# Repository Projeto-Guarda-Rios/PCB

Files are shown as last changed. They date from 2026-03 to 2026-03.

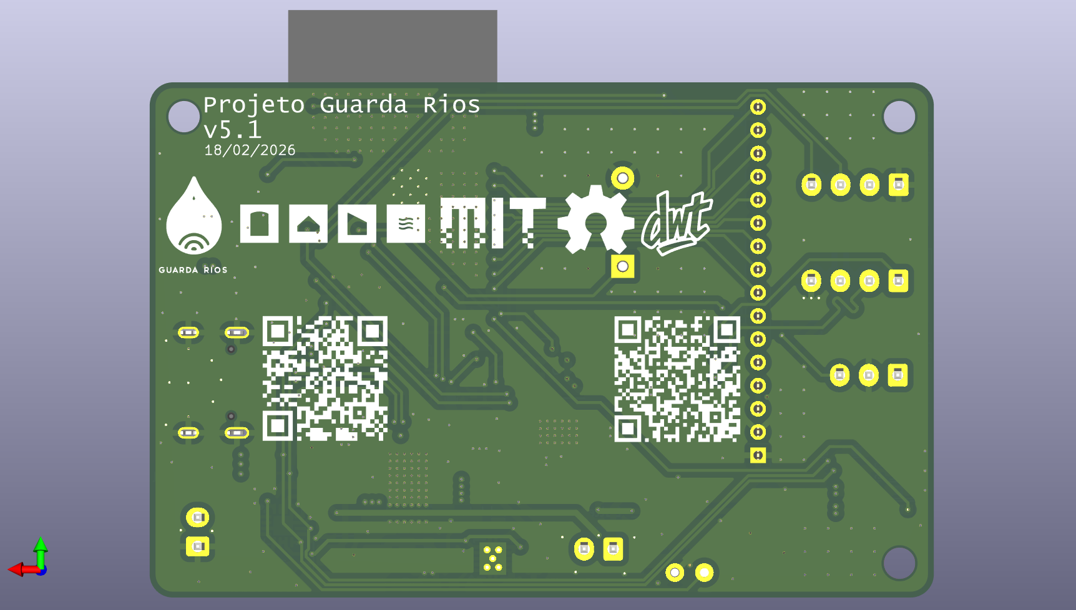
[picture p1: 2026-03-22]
PGR - PCB/Renders/PGR - 2.png

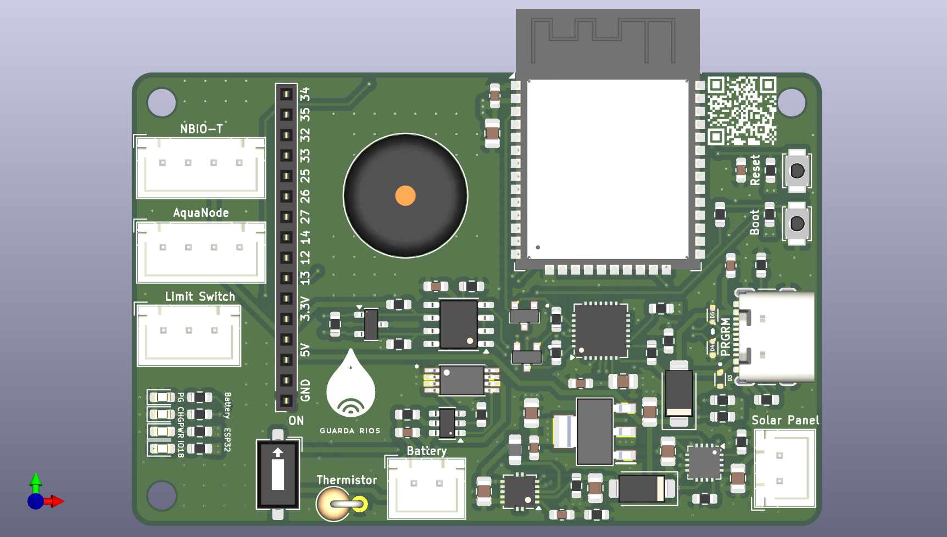
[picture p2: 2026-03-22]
PGR - PCB/Renders/PGR.png

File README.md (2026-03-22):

# Guarda-Rios PCB Repository

This repository contains all PCB design files for the **Guarda-Rios Project** — an open-source, low-cost, low-power water quality monitoring system. Multiple stations are deployed along a river so that parameter spikes between adjacent stations reveal precisely where pollution enters the waterway.

The system has two PCBs:

| Board | Role | Placement |
|---|---|---|
| **AquaNode PCB** | Submerged sensor node — reads water parameters and transmits them over RS-485 | Below waterline |
| **Main PCB (PGR)** | Station hub — receives RS-485 data, manages power (solar + 18650 Li-ion), and sends data to the cloud via NB-IoT | Above waterline |

> GitHub organisation: [github.com/Projeto-Guarda-Rios](https://github.com/Projeto-Guarda-Rios)
> Project site: [guarda-rios.pt](https://guarda-rios.pt) · Data portal: [data.guarda-rios.pt](https://data.guarda-rios.pt)

---

## Directory Structure

```
PCB/
├── AquaNode - PCB/          # AquaNode submerged sensor node
├── PGR - PCB/               # Main Station PCB
├── Datasheets/              # Component datasheets
├── Resources/               # Logos, SVGs, and images (silkscreen assets)
└── LICENSE
```

---

## AquaNode - PCB

The AquaNode is the submerged node of each station. It is built around an **STM32L053R8** microcontroller (ultra-low-power) and integrates a DS18B20 water temperature sensor (1-Wire) and a DFRobot SEN0554 turbidity sensor. Readings are encoded into the custom Guarda-Rios protocol and transmitted to the Main PCB over RS-485.

```
AquaNode - PCB/
├── Renders/                              # PNG renders of the current board
│   ├── AquaNode - PCB.png               #   Top-side render
│   └── AquaNode - PCB - 2.png           #   Bottom-side / alternate angle render
│
├── AquaNode - PCB.step                  # STEP model of the assembled board
├── AquaNode - PCB - Render.step         # STEP model used for rendering
├── AquaNode - PCB.stl                   # STL mesh of the board
│
└── AquaNode - PCB/                      # KiCAD project (current version)
    ├── AquaNode - PCB.kicad_pro         #   KiCAD project file  ← open this in KiCAD
    ├── AquaNode - PCB.kicad_pcb         #   PCB layout
    ├── AquaNode - PCB.kicad_sch         #   Schematic
    ├── footprints/                      #   Custom footprint library
    ├── symbols/                         #   Custom symbol library
    └── production/                      # Production files (PCBA) — current version
        ├── -v2.0.zip                    #   Gerbers + drill files (upload to JLCPCB)
        ├── -v2.0_bom.csv               #   Bill of Materials
        ├── -v2.0_positions.csv         #   Component placement (pick & place)
        ├── -v2.0_designators.csv       #   Designator mapping
        ├── netlist.ipc                  #   IPC netlist
        └── backups/                     #   Auto-generated production backups
```

**Key files:**
- Edit the PCB: `AquaNode - PCB/AquaNode - PCB/AquaNode - PCB.kicad_pro`
- Order the board: `AquaNode - PCB/AquaNode - PCB/production/-v2.0.zip`
- BOM for assembly: `AquaNode - PCB/AquaNode - PCB/production/-v2.0_bom.csv`
- Positions for assembly: `AquaNode - PCB/AquaNode - PCB/production/-v2.0_positions.csv`

---

## PGR - PCB

The Main PCB (PGR) is the above-water hub of each station. It is built around an **ESP32-WROOM-32D** and includes an RS-485 receiver, NB-IoT modem, BMS (battery management system), 18650 Li-ion charger, and solar charger — making each station fully self-sufficient in the field.

```
PGR - PCB/
├── Renders/                              # PNG renders of the current board
│   ├── PGR.png                          #   Top-side render
│   └── PGR - 2.png                      #   Bottom-side / alternate angle render
│
├── PGR.step                             # STEP model of the assembled board
├── PGR-Solder.step                      # STEP model showing solder joints
├── PGR.3mf                             # 3MF model (for 3D printing / Fusion 360)
│
├── PGR - PCB - v1.0-v4.0.zip           # Archived KiCAD projects (versions 1.0 – 4.0)
├── PGR - PCB - v5.0.zip                # Archived KiCAD project (version 5.0)
│
├── gerbers/                             # Gerber archives for previous board versions
│   ├── PGR-gerbers-v1.0.zip
│   ├── PGR-gerbers-v2.0.zip
│   ├── PGR-gerbers-v3.0.zip
│   ├── PGR-gerbers-v3.1.zip
│   ├── PGR-gerbers-v4.0.zip
│   ├── PGR-gerbers.zip                  #   (legacy export)
│   ├── PGR-F_Paste.zip                  #   Front paste layer export
│   └── PGR-PTH.zip                      #   PTH drill file export
│
└── PGR - PCB/                           # KiCAD project (current version)
    ├── PGR.kicad_pro                    #   KiCAD project file  ← open this in KiCAD
    ├── PGR.kicad_pcb                    #   PCB layout
    ├── PGR.kicad_sch                    #   Schematic
    ├── PGR-Library.kicad_sym           #   Custom symbol library
    ├── PGR-FootPrints.pretty/          #   Custom footprint library
    ├── footprints/                      #   Additional footprints
    ├── symbols/                         #   Additional symbols
    └── production/                      # Production files (PCBA) — current versions
        ├── PGR_PCB_v5.1.zip            #   Gerbers + drill files — latest (upload to JLCPCB)
        ├── PGR_PCB_v5.1_bom.csv        #   Bill of Materials — latest
        ├── PGR_PCB_v5.1_positions.csv  #   Component placement — latest
        ├── PGR_PCB_v5.1_designators.csv
        ├── PGR_PCB_v5.0.zip            #   Gerbers + drill files — v5.0
        ├── PGR_PCB_v5.0_bom.csv        #   Bill of Materials — v5.0
        ├── PGR_PCB_v5.0_positions.csv
        ├── PGR_PCB_v5.0_designators.csv
        ├── bom-JLCPCB Assembly Order.xls  # JLCPCB-formatted BOM for online ordering
        ├── bom.csv
        ├── designators.csv
        ├── positions.csv
        ├── netlist.ipc
        └── backups/                    # Auto-generated production backups
```

**Key files:**
- Edit the PCB: `PGR - PCB/PGR - PCB/PGR.kicad_pro`
- Order the board (latest): `PGR - PCB/PGR - PCB/production/PGR_PCB_v5.1.zip`
- BOM for assembly (latest): `PGR - PCB/PGR - PCB/production/PGR_PCB_v5.1_bom.csv`
- Positions for assembly (latest): `PGR - PCB/PGR - PCB/production/PGR_PCB_v5.1_positions.csv`
- Previous version gerbers: `PGR - PCB/gerbers/`

> Note: There are no current production files inside `PGR - PCB/gerbers/` — that directory holds archives of older board revisions only. Current production files are inside `PGR - PCB/PGR - PCB/production/`.

---

## Datasheets

Reference datasheets for ICs and components used across both PCBs.

```
Datasheets/
├── STM32L053C6.PDF                       # AquaNode MCU — STM32L053 datasheet
├── an4467-getting-started-with-stm32l0xx-hardware-development-stmicroelectronics.pdf
│                                         # STM32L0 hardware development guide (ST AppNote AN4467)
└── st485eb.pdf                           # ST485EB RS-485 transceiver (used on AquaNode)
```

---

## Resources

Images, SVGs, and logos used in PCB silkscreen layers or project documentation.

```
Resources/
├── guarda_rios_logo.svg / .png          # Official Guarda-Rios project logo
├── dwtLogo.svg                          # Designer logo
├── MIT_license_logo.svg / .png         # MIT license badge
├── open_source_logo.svg                 # Open-source hardware logo
├── open-source-hardware6230.logowik.com.webp
├── logo-colegio-ribadouro.png           # School/institution logo
│
├── AquaNodeBack.svg                     # AquaNode back silkscreen artwork
├── AquaNodeBack - Sem Logo.svg          # AquaNode back silkscreen (no logo variant)
├── BackSilkScreen.svg                   # Generic back silkscreen asset
│
├── AquaNode_v2_image_top.png            # AquaNode v2 board image — top
├── AquaNode_v2_image_bottom.png         # AquaNode v2 board image — bottom
├── PGR_v5.1_image_top.png              # PGR v5.1 board image — top
├── PGR_v5.1_image_bottom.png           # PGR v5.1 board image — bottom
│
└── Gemini_Generated_Image_iya1lhiya1lhiya1.png   # AI-generated concept image
```

---

## Hardware Summary

| Parameter | AquaNode PCB | Main PCB (PGR) |
|---|---|---|
| MCU | STM32L053R8 | ESP32-WROOM-32D |
| Sensors | DS18B20 (temp), DFRobot SEN0554 (turbidity) | — |
| Communication | RS-485 out (custom protocol) | RS-485 in · NB-IoT out |
| Power | From Main PCB via RS-485 cable | Solar + 18650 Li-ion (BMS + charger on-board) |
| Placement | Submerged | Above waterline |
| CAD tool | KiCAD | KiCAD |

---

## License

This project is fully open-source. See [`LICENSE`](LICENSE) for details.

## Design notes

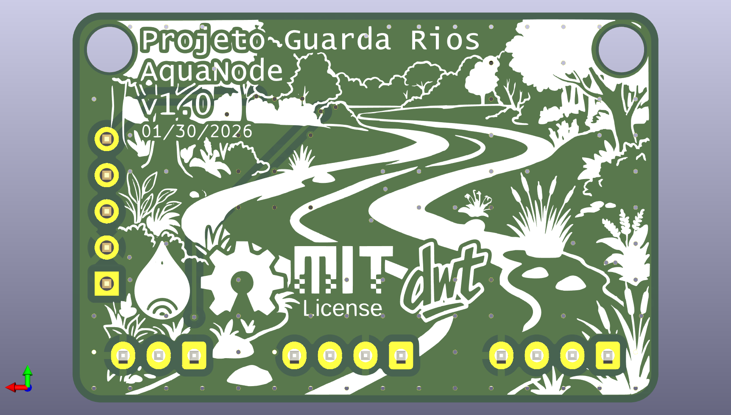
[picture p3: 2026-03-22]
AquaNode - PCB/Renders/AquaNode - PCB - 2.png

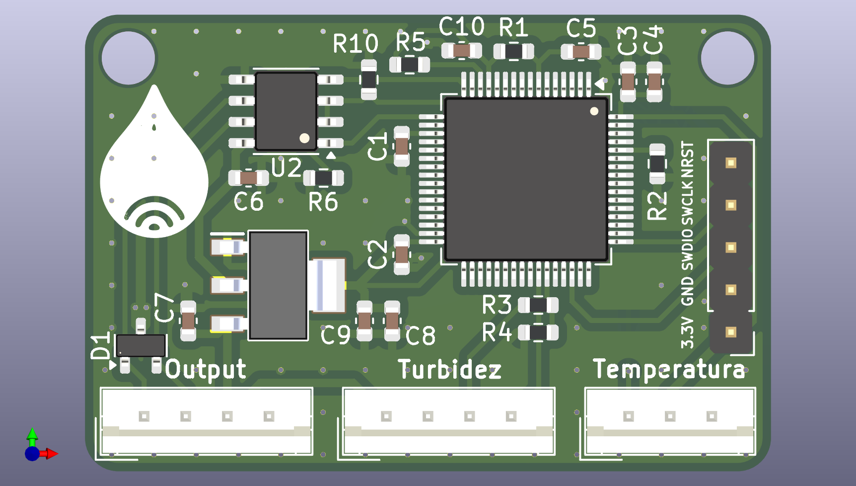
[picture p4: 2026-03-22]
AquaNode - PCB/Renders/AquaNode - PCB.png

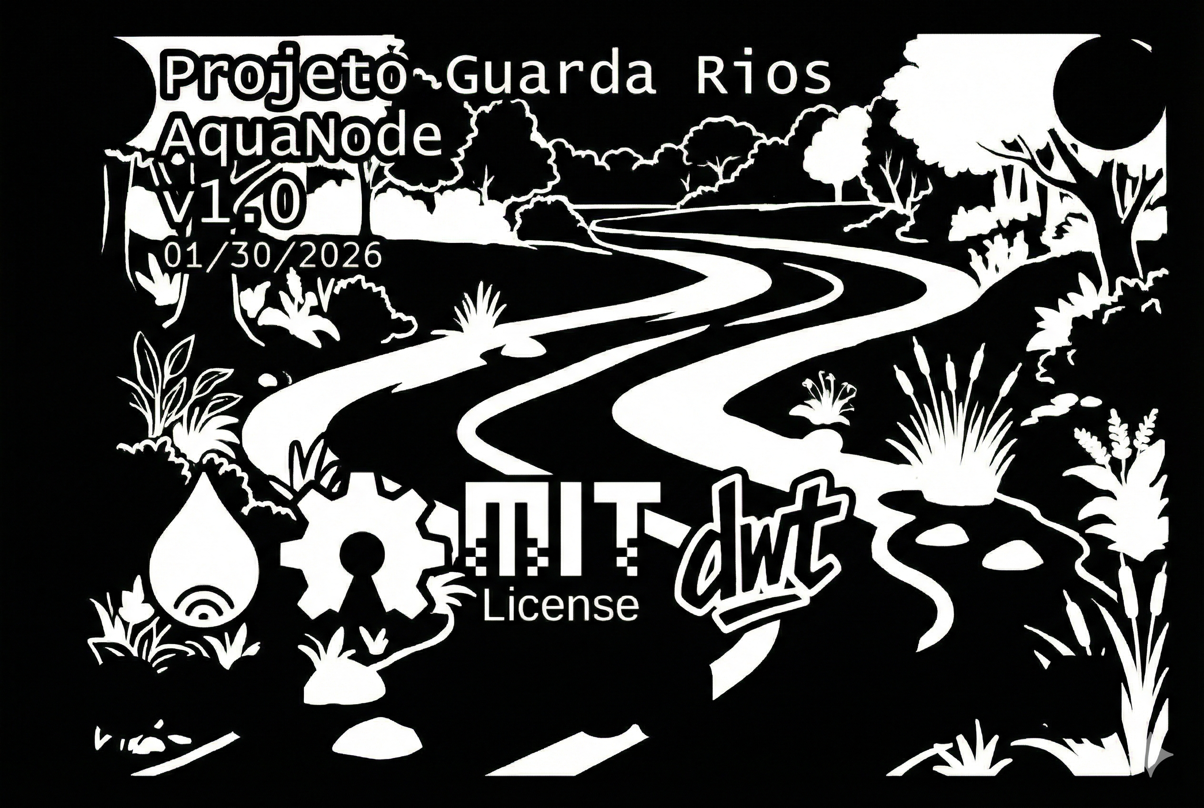
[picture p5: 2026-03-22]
Resources/Gemini_Generated_Image_iya1lhiya1lhiya1.png

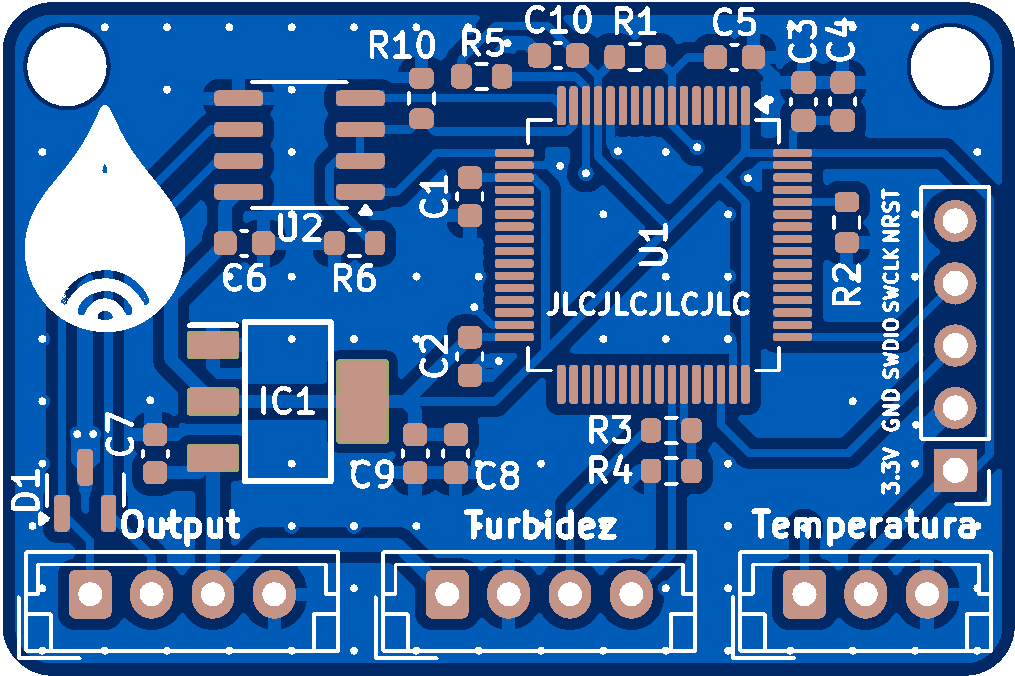
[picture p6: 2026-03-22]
Resources/AquaNode_v2_image_top.png

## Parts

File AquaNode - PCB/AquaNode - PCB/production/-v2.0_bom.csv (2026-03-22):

Designator | Footprint | Quantity | Value | LCSC Part #
C1, C10, C2, C3, C5, C6 | 0603 | 6 | 100nF
C4, C7, C8 | 0603 | 3 | 4.7uF
C9 | 0603 | 1 | 0.1uF
D1 | SOT-23 | 1 | SM712_SOT23
IC1 | SOT230P700X180-4N | 1 | AP2114H-3.3TRG1
J1 | JST_EH_B3B-EH-A_1x03_P2.50mm_Vertical | 1 | Conn_01x03_Socket
J2, J3 | JST_EH_B4B-EH-A_1x04_P2.50mm_Vertical | 2 | Conn_01x04_Socket
J5 | PinHeader_1x05_P2.54mm_Vertical | 1 | Conn_01x05_Socket
R1, R10, R2, R6 | 0603 | 4 | 10K
R3 | 0603 | 1 | 1.8K
R4 | 0603 | 1 | 3.3K
R5 | 0603 | 1 | 4.7K
U1 | LQFP-64_10x10mm_P0.5mm | 1 | STM32L053R8Tx
U2 | SOIC-8_3.9x4.9mm_P1.27mm | 1 | MAX3485

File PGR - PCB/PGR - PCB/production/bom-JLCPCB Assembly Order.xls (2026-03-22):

JLCPCB BOM Tool - BOM Matching
BOM name：bom-JLCPCB Assembly Order.xlsx |  |  | Download Time：2025-12-12 06:22:09 |  |  |  | * Our matching results are updated in real-time, but stock and prices may change. If it's been over 24 hours, please re-match before placing your order.
PCB Assembled Qty：5 |  |  | Est. Total Price：23.8928
Your BOM |  |  |  |  | Matched Parts |  |  |  |  |  |  | Order Information
Top Designator | Bottom Designator | Comment | Footprint | JLCPCB Part # | Matches | Part # | Manufacturer | Footprint | Description | Category | Warning | JLCPCB Part # | Product link | Lib Type | Qty | Source | Total Price ($)
BT1 |  | Battery | JST_XH_B2B-XH-A_1x02_P2.50mm_Vertical |  | Select by Customer | B2B-XH-A-GU | JST | 插件,P=2.5mm | -25℃~+85℃ 1 1x2P 2 2.5mm 250V 2P 3A 5.75mm 7.4mm 7mm Brass Gold K Pin PA66 Through Hole UL94V-0 White XH Plugin,P=2.5mm Wire To Board Connector ROHS | Wire To Board Connector | 1.The comment (B2B-XH-A-GU) of this part does not match the one (Battery) provided in your BOM. Please confirm; | C265283 | https://jlcpcb.com/partdetail/JST-B2B_XH_AGU/C265283 | Extended | 2 | 2 JLCPCB | 0.4794
BZ1 |  | Buzzer | Buzzer_12x9.5RM7.6 |  | Select by Customer | TMB12A24 | Jiangsu Huaneng Elec | 插件,D=12mm | -20℃~+70℃ 12mm 18V~26V 2.3kHz 24V 30mA 85dB 9.8mm Active Buzzer (Built-in Driving Circuit) Electromagnetic Plugin,D=12mm Buzzers ROHS | Buzzers |  | C96078 | https://jlcpcb.com/partdetail/Jiangsu_HuanengElec-TMB12A24/C96078 | Extended | 2 | 2 JLCPCB | 0.5434
C1,C10,C12,C15,C2,C3,C7 |  | 0.1uF | 0603 |  | Select by Customer | CL10B104KA8NNNC | Samsung Electro-Mechanics | 0603 | 100nF 25V X7R ±10% 0603 Multilayer Ceramic Capacitors MLCC - SMD/SMT ROHS | Multilayer Ceramic Capacitors MLCC - SMD/SMT | 1.The comment (CL10B104KA8NNNC) of this part does not match the one (0.1uF) provided in your BOM. Please confirm; | C1590 | https://jlcpcb.com/partdetail/1942-CL10B104KA8NNNC/C1590 | Extended | 24 | 24 JLCPCB | 0.0792
C8,C9 |  | 22uF | 0805 |  | Select by System | CL21A226MAQNNNE | Samsung Electro-Mechanics | 0805 | 22uF 25V X5R ±20% 0805 Multilayer Ceramic Capacitors MLCC - SMD/SMT ROHS | Multilayer Ceramic Capacitors MLCC - SMD/SMT |  | C45783 | https://jlcpcb.com/partdetail/46786-CL21A226MAQNNNE/C45783 | Basic | 20 | 20 JLCPCB | 0.426
C11 |  | 4.7uF | 0805 |  | Select by System | CL21A475KAQNNNE | Samsung Electro-Mechanics | 0805 | 25V 4.7uF X5R ±10% 0805 Multilayer Ceramic Capacitors MLCC - SMD/SMT ROHS | Multilayer Ceramic Capacitors MLCC - SMD/SMT |  | C1779 | https://jlcpcb.com/partdetail/2131-CL21A475KAQNNNE/C1779 | Basic | 20 | 20 JLCPCB | 0.238
C13,C14,C16,C4,C5,C6 |  | 10uF | 0805 |  | Select by System | CL21A106KAYNNNE | Samsung Electro-Mechanics | 0805 | 10uF 25V X5R ±10% 0805 Multilayer Ceramic Capacitors MLCC - SMD/SMT ROHS | Multilayer Ceramic Capacitors MLCC - SMD/SMT |  | C15850 | https://jlcpcb.com/partdetail/16532-CL21A106KAYNNNE/C15850 | Basic | 22 | 22 JLCPCB | 0.2156
D1,D2 |  | SS14 | D_SMA |  | Select by System | SS14 | MDD(Microdiode Semiconductor) | SMA(DO-214AC) | -55℃~+150℃ 1A 25A 300uA@40V 40V 550mV@1A Independent SMA(DO-214AC) Schottky Diodes ROHS | Schottky Diodes |  | C2480 | https://jlcpcb.com/partdetail/MDD_Microdiode_Semiconductor-SS14/C2480 | Basic | 14 | 14 JLCPCB | 0.2086
D3,D4,D5 |  | LESD5D5.0CT1G | TVS_LESD5D5.0CT1G |  | Select by System | LESD5D5.0CT1G | UMW(Youtai Semiconductor Co., Ltd.) | SOD-523 | -40℃~+125℃ 15pF 18.6V 1uA 5V 7.8V 9.4A@8/20us IEC 61000-4-2 TVS SOD-523 ESD and Surge Protection (TVS/ESD) ROHS | ESD And Surge Protection (TVS/ESD) |  | C5199850 | https://jlcpcb.com/partdetail/5885882-LESD5D50CT1G/C5199850 | Extended | 20 | 20 JLCPCB | 0.294
D8 |  | RED | 0603 |  | Select by System | KT-0603R | Hubei KENTO Elec | 0603 | -40℃~+85℃ 120° 2.4V 20mA 300mcd 40mW 615nm~630nm 645nm Red Water Clear 0603 LED Indication - Discrete ROHS | LED Indication - Discrete |  | C2286 | https://jlcpcb.com/partdetail/Hubei_KENTOElec-KT0603R/C2286 | Basic | 20 | 20 JLCPCB | 0.112
D10,D7,D9 |  | BLUE | 0603 |  | Select by System | XL-1608UBC-04 | XINGLIGHT | 0603 | 120° 20mA 3.3V 300mcd 455nm~475nm 470nm 70mW Blue Top-mount Water Clear 0603 LED Indication - Discrete ROHS | LED Indication - Discrete |  | C965807 | https://jlcpcb.com/partdetail/XINGLIGHT-XL_1608UBC04/C965807 | Extended | 20 | 20 JLCPCB | 0.07
IC1 |  | AP2114H-3.3TRG1 | SOT230P700X180-4N |  | Select by System | AP2114H-3.3TRG1 | Diodes Incorporated | SOT-223 | -40℃~+85℃@(Ta) 1 1A 3.3V 30uVrms 450mV@(1A) 65dB@(1kHz) 65uA 6V Fixed Over Current Protection Positive SOT-223 Voltage Regulators - Linear, Low Drop Out (LDO) Regulators ROHS | Voltage Regulators - Linear, Low Drop Out (LDO) Regulators |  | C150716 | https://jlcpcb.com/partdetail/DiodesIncorporated-AP2114H_33TRG1/C150716 | Extended | 4 | 4 JLCPCB | 1.074
J1 |  | Conn_01x16 | PinSocket_1x16_P2.00mm_Vertical |  | Select by Customer | 2541WV-16P | HanElectricity | 插件,P=2.54mm | -55℃~+105℃ 1 16P 1x16P 2.54mm 2.54mm 3mm 6mm Gold Pin Header Through Hole Plugin,P=2.54mm Pin Headers ROHS | Pin Headers |  | C25503134 | https://jlcpcb.com/partdetail/HanElectricity-2541WV16P/C25503134 | Extended | 0 | 0 JLCPCB | 0
J2,J3,J4,J5,J6,J7 |  | Conn_01x03 | JST_XH_B3B-XH-A_1x03_P2.50mm_Vertical |  | Select by Customer | B3B-XH-A(LF)(SN) | JST | 插件,P=2.5mm | -25℃~+85℃ 1 1x3P 2.5mm 250V 3 3A 3P 5.75mm 7mm 9.9mm Brass K Pin PA66 Through Hole Tin UL94V-0 White XH Plugin,P=2.5mm Wire To Board Connector ROHS | Wire To Board Connector |  | C144394 | https://jlcpcb.com/partdetail/JST-B3B_XH_A_LF_SN/C144394 | Extended | 13 | 13 JLCPCB | 0.5876
J8 |  | Conn_01x04 | JST_XH_B4B-XH-A_1x04_P2.50mm_Vertical |  | Select by Customer | B4B-XH-A(LF)(SN) | JST | 插件,P=2.5mm | -25℃~+85℃ 1 12.4mm 1x4P 2.5mm 250V 3A 4 4P 5.75mm 7mm Brass K Pin PA66 Through Hole Tin UL94V-0 White XH Plugin,P=2.5mm Wire To Board Connector ROHS | Wire To Board Connector |  | C144395 | https://jlcpcb.com/partdetail/JST-B4B_XH_A_LF_SN/C144395 | Extended | 3 | 3 JLCPCB | 0.1467
J9 |  | USB_C_Receptacle | USB_C_Receptacle_GCT_USB4105-xx-A_16P_TopMnt_Horizontal |  | Select by Customer | USB-306F | HOOYA | 插件 | -20℃~+60℃ 1 24P 3A Female Surface Mount, Right Angle Type-C Plugin USB Connectors ROHS | USB Connectors |  | C309341 | https://jlcpcb.com/partdetail/HOOYA-USB306F/C309341 | Extended | 2 | 2 JLCPCB | 1.23
J10 |  | Conn_01x02 | JST_XH_B2B-XH-A_1x02_P2.50mm_Vertical |  | Select by Customer | B2B-XH-A(LF)(SN) | JST | 插件,P=2.5mm | -25℃~+85℃ 1 1x2P 2 2.5mm 250V 2P 3A 5.75mm 7.4mm 7mm Brass K Pin PA66 Through Hole Tin UL94V-0 White XH Plugin,P=2.5mm Wire To Board Connector ROHS | Wire To Board Connector |  | C158012 | https://jlcpcb.com/partdetail/JST-B2B_XH_A_LF_SN/C158012 | Extended | 3 | 3 JLCPCB | 0.1014
L1 |  | L | 0805 |  | Select by Customer | FCI201209F-3R3K | TAI-TECH | SMD,1.2x2mm | 3.3uH ±10% SMD,1.2x2mm Inductors (SMD) ROHS | Inductors (SMD) | 1.The footprint (SMD,1.2x2mm) of this part does not match the one (0805) provided in your BOM. Please confirm; | C304236 | https://jlcpcb.com/partdetail/TAITECH-FCI201209F3R3K/C304236 | Extended | 20 | 20 JLCPCB | 0.254
Q1,Q2 |  | SS8050-G | TRANS_SS8050-G |  | Select by System | SS8050-G | Comchip | SOT-23 | 1 NPN 1.5A 100@10mA,1V 100MHz 100nA 25V 300mW 400mV@50mA,5mA 5V NPN SOT-23 Bipolar (BJT) ROHS | Bipolar (BJT) |  | C3199946 | https://jlcpcb.com/partdetail/Comchip-SS8050G/C3199946 | Extended | 5 | 5 JLCPCB | 0.3075
Q3 |  | FS8205A | SOP65P640X120-8N |  | Select by Customer | WSP8205 | Winsok Semicon | TSSOP-8 | -55℃~+150℃ 1 N-Channel 1.25W 100pF 1V 20V 27mΩ@10V,6A 550pF 6A 8.8nC@4.5V 85pF N-Channel TSSOP-8 MOSFETs ROHS | MOSFETs | 1.The comment (WSP8205) of this part does not match the one (FS8205A) provided in your BOM. Please confirm; | C86872 | https://jlcpcb.com/partdetail/WinsokSemicon-WSP8205/C86872 | Extended | 5 | 5 JLCPCB | 0.3535
R1 |  | 1.5K | 0603 |  | Select by Customer | 0603WAF1501T5E | UNI-ROYAL(Uniroyal Elec) | 0603 | -55℃~+155℃ 1.5kΩ 100mW 75V Thick Film Resistor ±1% ±100ppm/℃ 0603 Chip Resistor - Surface Mount ROHS | Chip Resistor - Surface Mount | 1.The comment (0603WAF1501T5E) of this part does not match the one (1.5K) provided in your BOM. Please confirm; | C22843 | https://jlcpcb.com/partdetail/23570-0603WAF1501T5E/C22843 | Basic | 20 | 20 JLCPCB | 0.022
R3 |  | 4.7kΩ | 0603 |  | Select by System | 0603WAF4701T5E | UNI-ROYAL(Uniroyal Elec) | 0603 | -55℃~+155℃ 100mW 4.7kΩ 75V Thick Film Resistor ±1% ±100ppm/℃ 0603 Chip Resistor - Surface Mount ROHS | Chip Resistor - Surface Mount |  | C23162 | https://jlcpcb.com/partdetail/23889-0603WAF4701T5E/C23162 | Basic | 20 | 20 JLCPCB | 0.022
R4,R5 |  | 5.1K | 0603 |  | Select by Customer | RC0603JR-075K1L | YAGEO | 0603 | -55℃~+155℃ 100mW 5.1kΩ 75V Thick Film Resistor ±100ppm/℃ ±5% 0603 Chip Resistor - Surface Mount ROHS | Chip Resistor - Surface Mount | 1.The comment (RC0603JR-075K1L) of this part does not match the one (5.1K) provided in your BOM. Please confirm; | C14677 | https://jlcpcb.com/partdetail/YAGEO-RC0603JR075K1L/C14677 | Extended | 20 | 20 JLCPCB | 0.022
R6 |  | 22.1K | 0603 |  | Select by Customer | 0603WAF2212T5E | UNI-ROYAL(Uniroyal Elec) | 0603 | -55℃~+155℃ 100mW 22.1kΩ 75V Thick Film Resistor ±1% ±100ppm/℃ 0603 Chip Resistor - Surface Mount ROHS | Chip Resistor - Surface Mount | 1.The comment (0603WAF2212T5E) of this part does not match the one (22.1K) provided in your BOM. Please confirm; | C25961 | https://jlcpcb.com/partdetail/26704-0603WAF2212T5E/C25961 | Extended | 20 | 20 JLCPCB | 0.022
R7 |  | 47.5K | 0603 |  | Select by Customer | 0603WAF4752T5E | UNI-ROYAL(Uniroyal Elec) | 0603 | -55℃~+155℃ 100mW 47.5kΩ 75V Thick Film Resistor ±1% ±100ppm/℃ 0603 Chip Resistor - Surface Mount ROHS | Chip Resistor - Surface Mount | 1.The comment (0603WAF4752T5E) of this part does not match the one (47.5K) provided in your BOM. Please confirm; | C23061 | https://jlcpcb.com/partdetail/23788-0603WAF4752T5E/C23061 | Extended | 20 | 20 JLCPCB | 0.022
R10,R15,R16,R19,R20,R9 |  | 10K | 0603 |  | Select by Customer | 0603WAJ0103T5E | UNI-ROYAL(Uniroyal Elec) | 0603 | -55℃~+155℃ 100mW 10kΩ 75V Thick Film Resistor ±100ppm/℃ ±5% 0603 Chip Resistor - Surface Mount ROHS | Chip Resistor - Surface Mount | 1.The comment (0603WAJ0103T5E) of this part does not match the one (10K) provided in your BOM. Please confirm; | C15401 | https://jlcpcb.com/partdetail/16079-0603WAJ0103T5E/C15401 | Extended | 22 | 22 JLCPCB | 0.0198
R11 |  | 100R | 0603 |  | Select by Customer | 0603WAF1000T5E | UNI-ROYAL(Uniroyal Elec) | 0603 | -55℃~+155℃ 100mW 100Ω 75V Thick Film Resistor ±1% ±100ppm/℃ 0603 Chip Resistor - Surface Mount ROHS | Chip Resistor - Surface Mount | 1.The comment (0603WAF1000T5E) of this part does not match the one (100R) provided in your BOM. Please confirm; | C22775 | https://jlcpcb.com/partdetail/23502-0603WAF1000T5E/C22775 | Basic | 20 | 20 JLCPCB | 0.02
R12 |  | 22R | 0603 |  | Select by Customer | 0603WAJ0220T5E | UNI-ROYAL(Uniroyal Elec) | 0603 | -55℃~+155℃ 100mW 22Ω 75V Thick Film Resistor ±200ppm/℃ ±5% 0603 Chip Resistor - Surface Mount ROHS | Chip Resistor - Surface Mount | 1.The comment (0603WAJ0220T5E) of this part does not match the one (22R) provided in your BOM. Please confirm; | C1203 | https://jlcpcb.com/partdetail/1555-0603WAJ0220T5E/C1203 | Extended | 20 | 20 JLCPCB | 0.018
R13,R21,R24 |  | 33R | 0603 |  | Select by Customer | 0603WAF330JT5E | UNI-ROYAL(Uniroyal Elec) | 0603 | -55℃~+155℃ 100mW 33Ω 75V Thick Film Resistor ±1% ±100ppm/℃ 0603 Chip Resistor - Surface Mount ROHS | Chip Resistor - Surface Mount | 1.The comment (0603WAF330JT5E) of this part does not match the one (33R) provided in your BOM. Please confirm; | C23140 | https://jlcpcb.com/partdetail/23867-0603WAF330JT5E/C23140 | Basic | 20 | 20 JLCPCB | 0.022
R14 |  | 150R | 0603 |  | Select by Customer | 0603WAF1500T5E | UNI-ROYAL(Uniroyal Elec) | 0603 | -55℃~+155℃ 100mW 150Ω 75V Thick Film Resistor ±1% ±100ppm/℃ 0603 Chip Resistor - Surface Mount ROHS | Chip Resistor - Surface Mount | 1.The comment (0603WAF1500T5E) of this part does not match the one (150R) provided in your BOM. Please confirm; | C22808 | https://jlcpcb.com/partdetail/23535-0603WAF1500T5E/C22808 | Basic | 20 | 20 JLCPCB | 0.022
R17,R2,R8 |  | 2K | 0603 |  | Select by Customer | 0603WAF2001T5E | UNI-ROYAL(Uniroyal Elec) | 0603 | -55℃~+155℃ 100mW 2kΩ 75V Thick Film Resistor ±1% ±100ppm/℃ 0603 Chip Resistor - Surface Mount ROHS | Chip Resistor - Surface Mount | 1.The comment (0603WAF2001T5E) of this part does not match the one (2K) provided in your BOM. Please confirm; | C22975 | https://jlcpcb.com/partdetail/23702-0603WAF2001T5E/C22975 | Basic | 20 | 20 JLCPCB | 0.02
R22 |  | 900K | 0603 |  | Select by Customer | RT1206BRE07900KL | YAGEO | 1206 | -55℃~+155℃ 200V 250mW 900kΩ Thin Film Resistor ±0.1% ±50ppm/℃ 1206 Chip Resistor - Surface Mount ROHS | Chip Resistor - Surface Mount | 1.The footprint (1206) of this part does not match the one (0603) provided in your BOM. Please confirm; 2.The comment (RT1206BRE07900KL) of this part does not match the one (900K) provided in your BOM. Please confirm; | C871499 | https://jlcpcb.com/partdetail/YAGEO-RT1206BRE07900KL/C871499 | Extended | 5 | 5 JLCPCB | 0.2515
R23 |  | 100K | 0603 |  | Select by Customer | RC0603FR-07100KL | YAGEO | 0603 | -55℃~+155℃ 100kΩ 100mW 75V Thick Film Resistor ±1% ±100ppm/℃ 0603 Chip Resistor - Surface Mount ROHS | Chip Resistor - Surface Mount | 1.The comment (RC0603FR-07100KL) of this part does not match the one (100K) provided in your BOM. Please confirm; | C14675 | https://jlcpcb.com/partdetail/YAGEO-RC0603FR07100KL/C14675 | Extended | 20 | 20 JLCPCB | 0.02
R25,R26,R27 |  | 5K | 0603 |  | Select by Customer | RTT035001FTP | RALEC | 0603 | -55℃~+155℃ 100mW 5kΩ 75V Thick Film Resistor ±1% ±100ppm/℃ 0603 Chip Resistor - Surface Mount ROHS | Chip Resistor - Surface Mount | 1.The comment (RTT035001FTP) of this part does not match the one (5K) provided in your BOM. Please confirm; | C166926 | https://jlcpcb.com/partdetail/RALEC-RTT035001FTP/C166926 | Extended | 20 | 20 JLCPCB | 0.024
SW1 |  | BOOT | SW_SPST_B3U-1000P |  | Select by Customer | B3U-1000P | Omron Electronics | SMD,3x2.5mm | -25℃~+70℃ 1.53N 1.6mm 12V 2.5mm 3mm 50mA Round Button SMD(SMT) Tab SPST Surface Mount,Vertical SMD,3x2.5mm Tactile Switches ROHS | Tactile Switches | 1.Multiple lines in the BOM have been matched to the same part. Please check if the matching is correct. ; | C231329 | https://jlcpcb.com/partdetail/OmronElectronics-B3U1000P/C231329 | Extended | 6 | 6 JLCPCB | 0.8958
SW2 |  | RESET | SW_SPST_B3U-1000P |  | Select by Customer | B3U-1000P | Omron Electronics | SMD,3x2.5mm | -25℃~+70℃ 1.53N 1.6mm 12V 2.5mm 3mm 50mA Round Button SMD(SMT) Tab SPST Surface Mount,Vertical SMD,3x2.5mm Tactile Switches ROHS | Tactile Switches | 1.The comment (B3U-1000P) of this part does not match the one (RESET) provided in your BOM. Please confirm; 2.Multiple lines in the BOM have been matched to the same part. Please check if the matching is correct. ; | C231329 | https://jlcpcb.com/partdetail/OmronElectronics-B3U1000P/C231329 | Extended | 6 | 6 JLCPCB | 0.8958
SW4 |  | SW_SPDT | SW_DIP_SPSTx01_Slide_6.7x4.1mm_W6.73mm_P2.54mm_LowProfile_JPin |  | Select by Customer | DSIC01LSGET | DongGuan KINGTEK Industrial Co.,LTD | SMD | 1 Black SPST Slide, Rocked SMD DIP Switches ROHS | DIP Switches |  | C54948 | https://jlcpcb.com/partdetail/55973-DSIC01LSGET/C54948 | Extended | 2 | 2 JLCPCB | 0.735
U1 |  | BQ24074RGT | VQFN-16-1EP_3x3mm_P0.5mm_EP1.6x1.6mm |  | Select by Customer | BQ24074RGTR | Texas Instruments | QFN-16-EP(3x3) | -40℃~+125℃ 1 1.5A 4.2V 4.35V~10.2V 6.5uA Charging IC Lithium Battery Support QFN-16-EP(3x3) Battery Management ROHS | Battery Management | 1.The comment (BQ24074RGTR) of this part does not match the one (BQ24074RGT) provided in your BOM. Please confirm; | C54313 | https://jlcpcb.com/partdetail/TexasInstruments-BQ24074RGTR/C54313 | Extended | 2 | 2 JLCPCB | 1.878
U2 |  | ~ | MSOP10 |  | Select by Customer | ADS1115IDGSR | Texas Instruments | VSSOP-10 | -40℃~+125℃ 16 16Hz 1LSB 2 2.048V 2V~5.5V 500nA Built-in Built-in I2C Sigma-Delta Support Yes VSSOP-10 Analog to Digital Converters (ADC) ROHS | Analog To Digital Converters (ADC) |  | C37593 | https://jlcpcb.com/partdetail/TexasInstruments-ADS1115IDGSR/C37593 | Extended | 2 | 2 JLCPCB | 1.617
U3 |  | TPS61200DRC | Texas_S-PVSON-N10_ThermalVias |  | Select by System | TPS61200DRCR | Texas Instruments | VSON-10-EP(3x3) | -40℃~+85℃@(TA) 1 1.65MHz 1.8V~5.5V 300mV~5.5V 70uA Adjustable Boost Boost Built-in Yes VSON-10-EP(3x3) DC-DC Converters ROHS | DC-DC Converters |  | C140320 | https://jlcpcb.com/partdetail/TexasInstruments-TPS61200DRCR/C140320 | Extended | 2 | 2 JLCPCB | 2.505
U4 |  | CP2102N-Axx-xQFN28 | QFN-28-1EP_5x5mm_P0.5mm_EP3.35x3.35mm |  | Select by Customer | CP2102N-A02-GQFN28R | SKYWORKS/SILICON LABS | QFN-28-EP(5x5) | -40℃~+85℃@(Ta) 1.3uA 3V~3.6V 9.5mA USB 2.0 USB to UART QFN-28-EP(5x5) USB Converters ROHS | USB Converters |  | C964632 | https://jlcpcb.com/partdetail/1049893-CP2102N_A02GQFN28R/C964632 | Extended | 2 | 0 My Parts | 0
U5 |  | ESP32-WROOM-32E | ESP32-WROOM-32D |  | Select by Customer | ESP32-WROOM-32E-N8 | Espressif Systems | SMD,25.5x18mm | SMD,25.5x18mm WiFi Modules ROHS | WiFi Modules | 1.The comment (ESP32-WROOM-32E-N8) of this part does not match the one (ESP32-WROOM-32E) provided in your BOM. Please confirm; | C701342 | https://jlcpcb.com/partdetail/EspressifSystems-ESP32_WROOM_32EN8/C701342 | Extended | 2 | 2 JLCPCB | 7.917
U6 |  | DW01A | SOT-23-6 |  | Select by System | DW01A | HL | SOT23-6 | -40℃~+85℃ 1 1.5V~10V 2.5V 4.3V 700nA Lithium Battery Protection IC Support SOT23-6 Battery Management ROHS | Battery Management |  | C18164398 | https://jlcpcb.com/partdetail/HL-DW01A/C18164398 | Extended | 10 | 10 JLCPCB | 0.201
TH1 |  | Thermistor_NTC10 kΩ25 °C | R_Axial_DIN0309_L9.0mm_D3.2mm_P2.54mm_Vertical |  | No matches | No Part Selected

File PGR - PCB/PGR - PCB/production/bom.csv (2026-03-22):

Designator | Footprint | Quantity | Value | LCSC Part #
BT1 | JST_XH_B2B-XH-A_1x02_P2.50mm_Vertical | 1 | Battery
BZ1 | Buzzer_12x9.5RM7.6 | 1 | Buzzer
C1, C10, C12, C15, C2, C3, C7 | 0603 | 7 | 0.1uF
C11 | 0805 | 1 | 4.7uF
C13, C14, C16, C4, C5, C6 | 0805 | 6 | 10uF
C8, C9 | 0805 | 2 | 22uF
D1, D2 | D_SMA | 2 | SS14
D10, D7, D9 | 0603 | 3 | BLUE
D3, D4, D5 | TVS_LESD5D5.0CT1G | 3 | LESD5D5.0CT1G
D8 | 0603 | 1 | RED
IC1 | SOT230P700X180-4N | 1 | AP2114H-3.3TRG1
J1 | PinSocket_1x16_P2.00mm_Vertical | 1 | Conn_01x16
J10 | JST_XH_B2B-XH-A_1x02_P2.50mm_Vertical | 1 | Conn_01x02
J2, J3, J4, J5, J6, J7 | JST_XH_B3B-XH-A_1x03_P2.50mm_Vertical | 6 | Conn_01x03
J8 | JST_XH_B4B-XH-A_1x04_P2.50mm_Vertical | 1 | Conn_01x04
J9 | USB_C_Receptacle_GCT_USB4105-xx-A_16P_TopMnt_Horizontal | 1 | USB_C_Receptacle
L1 | 0805 | 1 | L
Q1, Q2 | TRANS_SS8050-G | 2 | SS8050-G
Q3 | SOP65P640X120-8N | 1 | FS8205A
R1 | 0603 | 1 | 1.5K
R10, R15, R16, R19, R20, R9 | 0603 | 6 | 10K
R11 | 0603 | 1 | 100R
R12 | 0603 | 1 | 22R
R13, R21, R24 | 0603 | 3 | 33R
R14 | 0603 | 1 | 150R
R17, R2, R8 | 0603 | 3 | 2K
R22 | 0603 | 1 | 900K
R23 | 0603 | 1 | 100K
R25, R26, R27 | 0603 | 3 | 5K
R3 | 0603 | 1 | 4.7kΩ
R4, R5 | 0603 | 2 | 5.1K
R6 | 0603 | 1 | 22.1K
R7 | 0603 | 1 | 47.5K
SW1 | SW_SPST_B3U-1000P | 1 | BOOT
SW2 | SW_SPST_B3U-1000P | 1 | RESET
SW4 | SW_DIP_SPSTx01_Slide_6.7x4.1mm_W6.73mm_P2.54mm_LowProfile_JPin | 1 | SW_SPDT
TH1 | R_Axial_DIN0309_L9.0mm_D3.2mm_P2.54mm_Vertical | 1 | Thermistor_NTC 10 kΩ 25 °C
U1 | VQFN-16-1EP_3x3mm_P0.5mm_EP1.6x1.6mm | 1 | BQ24074RGT
U2 | MSOP10 | 1 | ~
U3 | Texas_S-PVSON-N10_ThermalVias | 1 | TPS61200DRC
U4 | QFN-28-1EP_5x5mm_P0.5mm_EP3.35x3.35mm | 1 | CP2102N-Axx-xQFN28
U5 | ESP32-WROOM-32D | 1 | ESP32-WROOM-32E
U6 | SOT-23-6 | 1 | DW01A

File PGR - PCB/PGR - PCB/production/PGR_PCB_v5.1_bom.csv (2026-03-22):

Designator | Footprint | Quantity | Value | LCSC Part #
BT1 | JST_XH_B2B-XH-A_1x02_P2.50mm_Vertical | 1 | Battery
BZ1 | Buzzer_12x9.5RM7.6 | 1 | Buzzer
C1, C10, C12, C15, C2, C3, C7 | 0603 | 7 | 0.1uF
C11 | 0805 | 1 | 4.7uF
C13, C14, C4, C5, C6 | 0805 | 5 | 10uF
C17 | 0603 | 1 | 100nF
C8, C9 | 0805 | 2 | 22uF
D1, D2 | D_SMA | 2 | SS14
D10, D7, D9 | 0603 | 3 | BLUE
D3, D4, D5 | TVS_LESD5D5.0CT1G | 3 | LESD5D5.0CT1G
D6 | SOT-23 | 1 | SM712_SOT23
D8 | 0603 | 1 | RED
IC1 | SOT230P700X180-4N | 1 | AP2114H-3.3TRG1
J1 | PinSocket_1x16_P2.00mm_Vertical | 1 | Conn_01x16
J10 | JST_XH_B2B-XH-A_1x02_P2.50mm_Vertical | 1 | Conn_01x02
J11, J8 | JST_XH_B4B-XH-A_1x04_P2.50mm_Vertical | 2 | Conn_01x04
J7 | JST_XH_B3B-XH-A_1x03_P2.50mm_Vertical | 1 | Conn_01x03
J9 | USB_C_Receptacle_GCT_USB4105-xx-A_16P_TopMnt_Horizontal | 1 | USB_C_Receptacle
L1 | 0805 | 1 | L
Q1, Q2 | TRANS_SS8050-G | 2 | SS8050-G
Q3 | SOP65P640X120-8N | 1 | FS8205A
R1 | 0603 | 1 | 1.5K
R10, R15, R16, R18, R19, R20, R28, R29, R9 | 0603 | 9 | 10K
R11 | 0603 | 1 | 100R
R12 | 0603 | 1 | 22R
R13, R21, R24 | 0603 | 3 | 33R
R14 | 0603 | 1 | 150R
R17, R2, R8 | 0603 | 3 | 2K
R22 | 0603 | 1 | 900K
R23 | 0603 | 1 | 100K
R3 | 0603 | 1 | 120R
R4, R5 | 0603 | 2 | 5.1K
R6 | 0603 | 1 | 22.1K
R7 | 0603 | 1 | 47.5K
SW1 | SW_SPST_B3U-1000P | 1 | BOOT
SW2 | SW_SPST_B3U-1000P | 1 | RESET
SW4 | SW_DIP_SPSTx01_Slide_6.7x4.1mm_W6.73mm_P2.54mm_LowProfile_JPin | 1 | SW_SPDT
TH1 | R_Axial_DIN0309_L9.0mm_D3.2mm_P2.54mm_Vertical | 1 | Thermistor_NTC 10 kΩ 25 °C
U1 | VQFN-16-1EP_3x3mm_P0.5mm_EP1.6x1.6mm | 1 | BQ24074RGT
U3 | Texas_S-PVSON-N10_ThermalVias | 1 | TPS61200DRC
U4 | QFN-28-1EP_5x5mm_P0.5mm_EP3.35x3.35mm | 1 | CP2102N-Axx-xQFN28
U5 | ESP32-WROOM-32D | 1 | ESP32-WROOM-32E
U6 | SOT-23-6 | 1 | DW01A
U8 | SOIC-8_3.9x4.9mm_P1.27mm | 1 | MAX3485

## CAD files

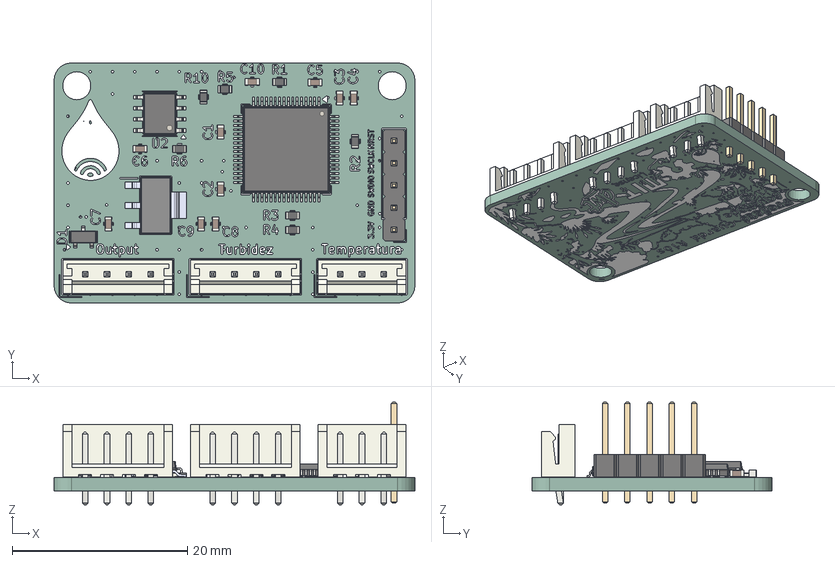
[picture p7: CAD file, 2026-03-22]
AquaNode - PCB/AquaNode - PCB.step
41.2 x 27.4 x 11.7 mm
R_0603_1608Metric x 7
AP2114H-3.3TRG1
C_0603_1608Metric x 10
PinHeader_1x05_P2.54mm_Vertical
SOT-23
JST_EH_B4B-EH-A_1x04_P2.50mm_Vertical x 2
SOIC-8_3.9x4.9mm_P1.27mm
LQFP-64_10x10mm_P0.5mm
JST_EH_B3B-EH-A_1x03_P2.50mm_Vertical
AquaNode - PCB_silkscreen
AquaNode - PCB_PCB

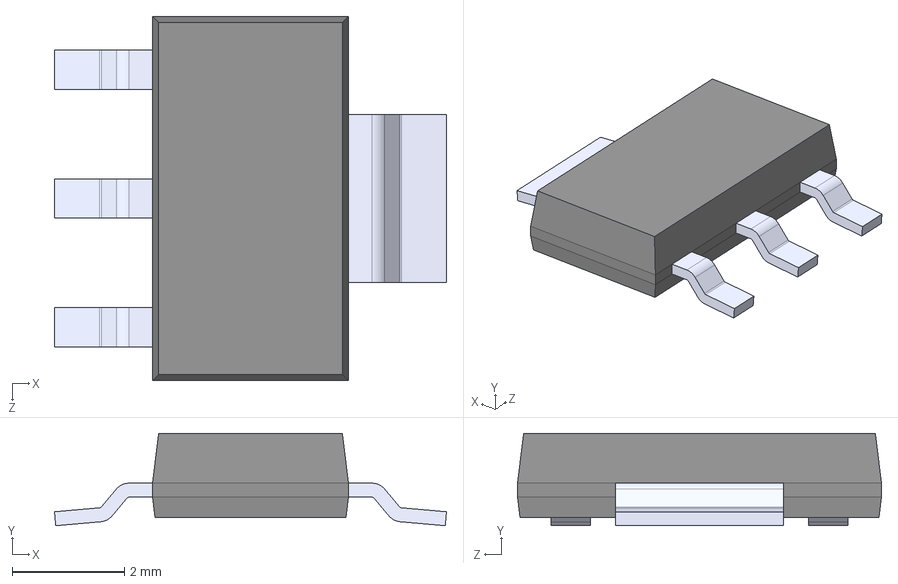
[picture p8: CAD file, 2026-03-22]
AquaNode - PCB/AquaNode - PCB/footprints/AP2114H-3.3TRG1/AP2114H-3.3TRG1.step
7.00 x 1.65 x 6.50 mm

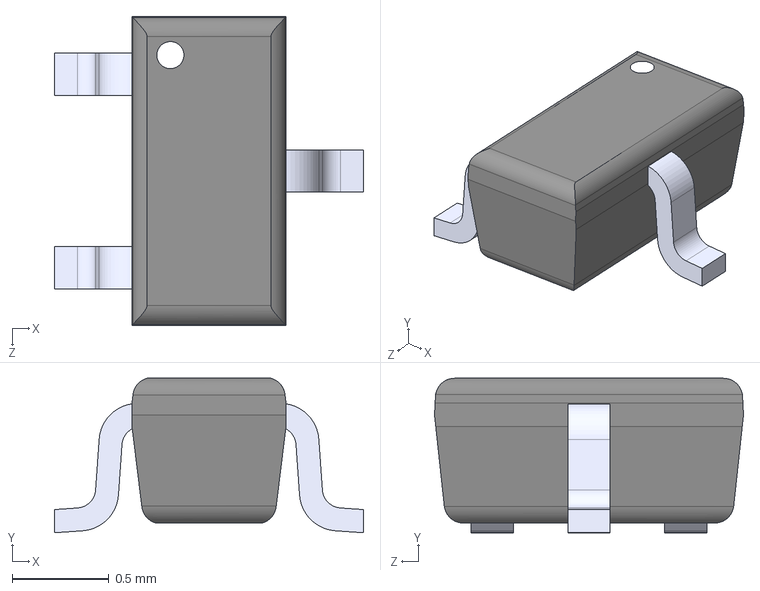
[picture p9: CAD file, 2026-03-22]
PGR - PCB/PGR - PCB/footprints/2N7002T-7-F/2N7002T-7-F.step
1.60 x 0.8 x 1.60 mm

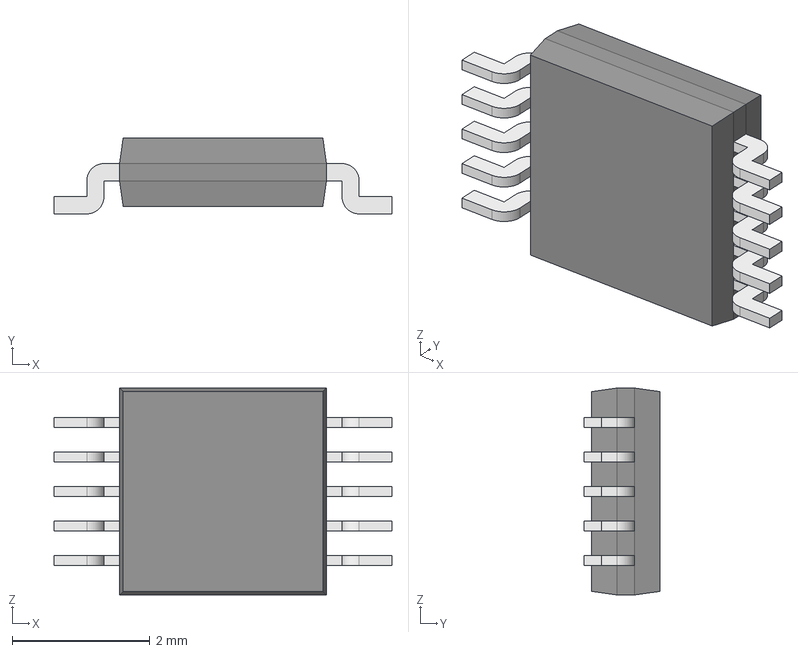
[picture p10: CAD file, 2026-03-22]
PGR - PCB/PGR - PCB/footprints/ADS1115/ADS1115.step
4.90 x 1.10 x 3.00 mm
Body001 (Mirror #1) x 5
XY-plane x 12
X-axis x 12

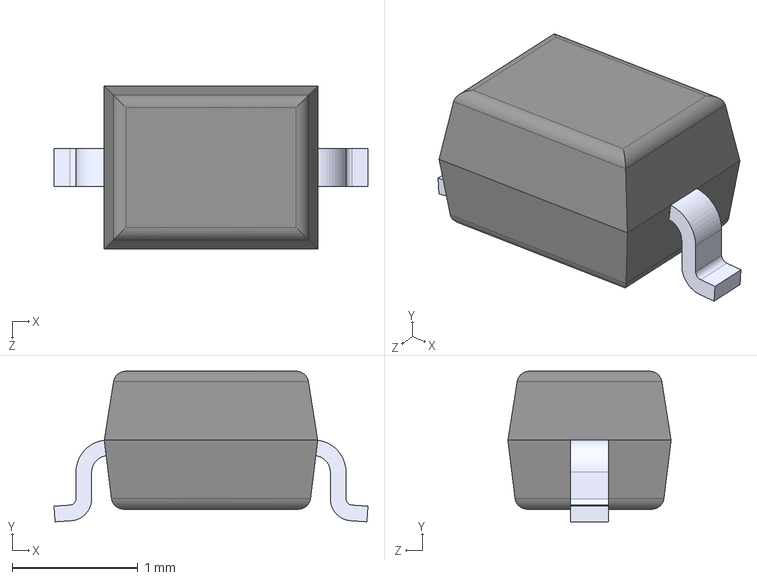
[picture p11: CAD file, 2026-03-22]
PGR - PCB/PGR - PCB/footprints/BAT760-7/BAT760-7.step
2.50 x 1.20 x 1.30 mm

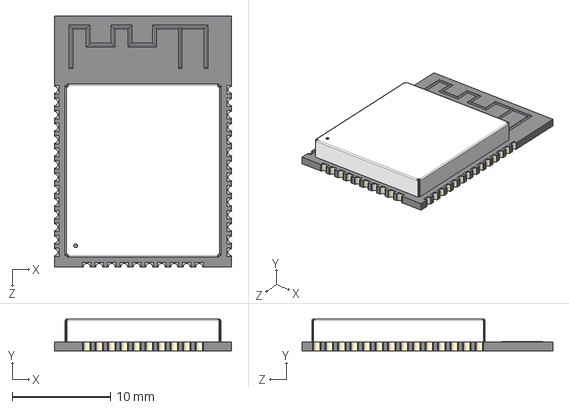
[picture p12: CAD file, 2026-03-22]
PGR - PCB/PGR - PCB/footprints/ESP32-WROOM-32D/ESP32-WROOM-32D--3DModel-STEP-510211.STEP
18.0 x 3.25 x 25.5 mm

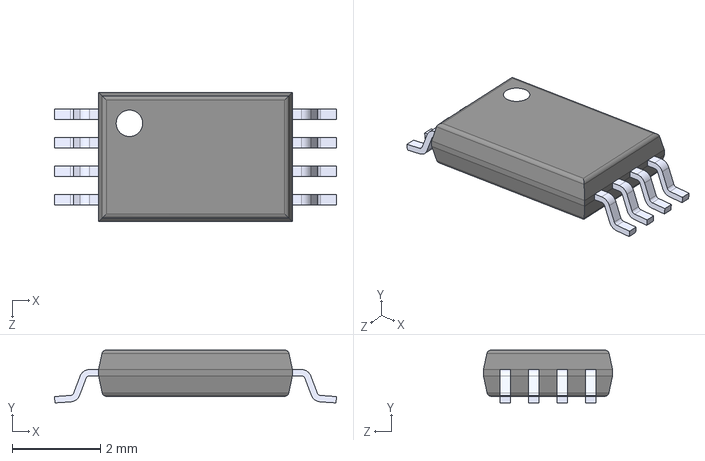
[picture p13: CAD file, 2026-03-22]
PGR - PCB/PGR - PCB/footprints/FS8205A/FS8205A.step
6.40 x 1.20 x 2.93 mm

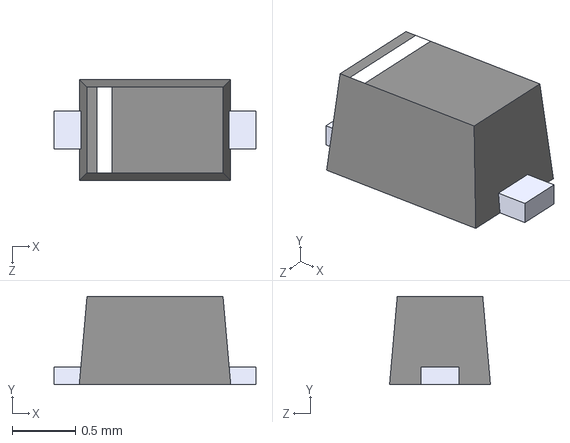
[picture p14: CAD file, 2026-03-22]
PGR - PCB/PGR - PCB/footprints/LESD5D5.0CT1G/LESD5D5.0CT1G.step
1.60 x 0.7 x 0.8 mm

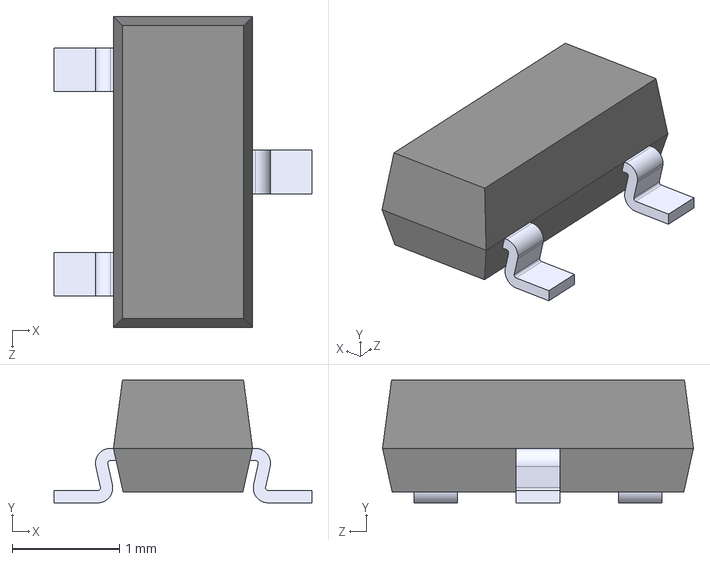
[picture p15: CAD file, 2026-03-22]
PGR - PCB/PGR - PCB/footprints/SS8050-G/SS8050-G.step
2.40 x 1.14 x 2.90 mm

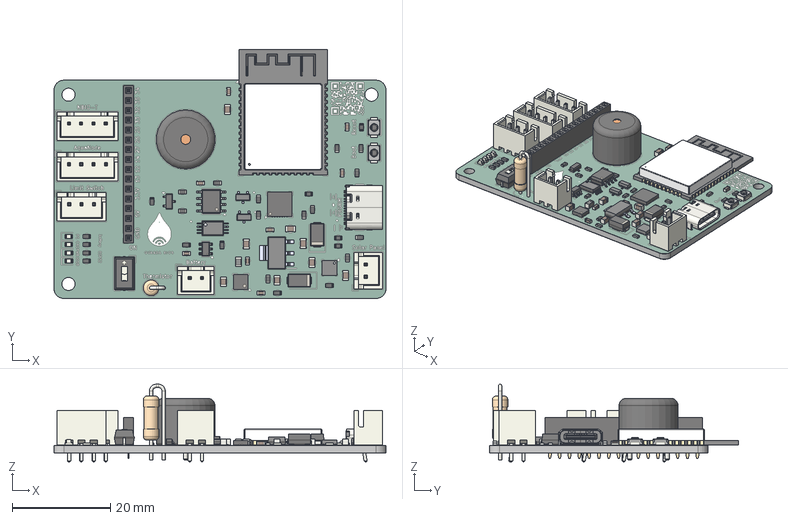
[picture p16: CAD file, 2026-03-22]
PGR - PCB/PGR-Solder.step
67.5 x 50.6 x 15.8 mm
Buzzer_12x9.5RM7.6
R_0603_1608Metric x 26
JST_XH_B2B-XH-A_1x02_P2.50mm_Vertical x 2
SS8050-G x 2
Texas_S-PVSON-N10
C_0603_1608Metric x 8
SW_DIP_SPSTx01_Slide_6.7x4.1mm_W6.73mm_P2.54mm_LowProfile_JPin
USB_C_Receptacle_GCT_USB4105-xx-A_16P_TopMnt_Horizontal
C_0805_2012Metric x 8
BQ24074RGTR
ESP32-WROOM-32D--3DModel-STEP-510211
JST_XH_B4B-XH-A_1x04_P2.50mm_Vertical x 2
JST_XH_B3B-XH-A_1x03_P2.50mm_Vertical
SOIC-8_3.9x4.9mm_P1.27mm
LED_0603_1608Metric x 4
SOT-23-6
L_0805_2012Metric
D_SMA x 2
FS8205A
SW_SPST_B3U-1000P x 2
AP2114H-3.3TRG1
R_Axial_DIN0309_L9.0mm_D3.2mm_P2.54mm_Vertical
PinSocket_1x16_P2.00mm_Vertical
QFN-28-1EP_5x5mm_P0.5mm_EP3.35x3.35mm
SOT-23
PGR_silkscreen
PGR_soldermask
PGR_PCB

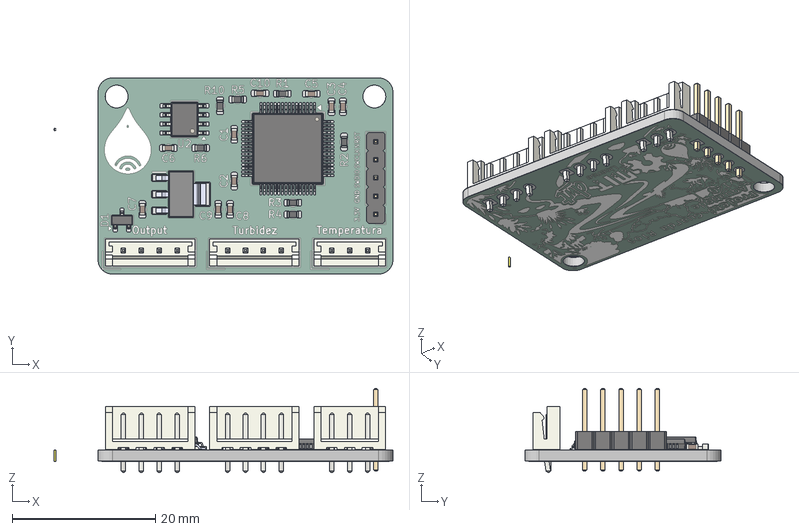
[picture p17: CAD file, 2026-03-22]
AquaNode - PCB/AquaNode - PCB - Render.step
47.3 x 27.4 x 11.7 mm
R_0603_1608Metric x 7
AP2114H-3.3TRG1
C_0603_1608Metric x 10
PinHeader_1x05_P2.54mm_Vertical
SOT-23
JST_EH_B4B-EH-A_1x04_P2.50mm_Vertical x 2
SOIC-8_3.9x4.9mm_P1.27mm
LQFP-64_10x10mm_P0.5mm
JST_EH_B3B-EH-A_1x03_P2.50mm_Vertical
AquaNode - PCB_copper
AquaNode - PCB_pad
AquaNode - PCB_via
AquaNode - PCB_silkscreen
AquaNode - PCB_soldermask
AquaNode - PCB_PCB

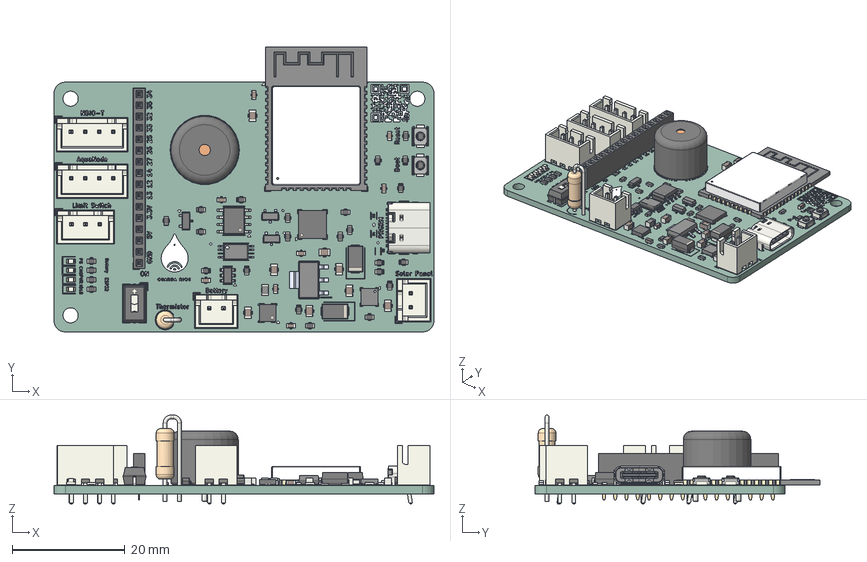
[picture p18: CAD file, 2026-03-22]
PGR - PCB/PGR.step
67.5 x 50.6 x 15.8 mm
Buzzer_12x9.5RM7.6
R_0603_1608Metric x 26
JST_XH_B2B-XH-A_1x02_P2.50mm_Vertical x 2
SS8050-G x 2
Texas_S-PVSON-N10
C_0603_1608Metric x 8
SW_DIP_SPSTx01_Slide_6.7x4.1mm_W6.73mm_P2.54mm_LowProfile_JPin
USB_C_Receptacle_GCT_USB4105-xx-A_16P_TopMnt_Horizontal
C_0805_2012Metric x 8
BQ24074RGTR
ESP32-WROOM-32D--3DModel-STEP-510211
JST_XH_B4B-XH-A_1x04_P2.50mm_Vertical x 2
JST_XH_B3B-XH-A_1x03_P2.50mm_Vertical
SOIC-8_3.9x4.9mm_P1.27mm
LED_0603_1608Metric x 4
SOT-23-6
L_0805_2012Metric
D_SMA x 2
FS8205A
SW_SPST_B3U-1000P x 2
AP2114H-3.3TRG1
R_Axial_DIN0309_L9.0mm_D3.2mm_P2.54mm_Vertical
PinSocket_1x16_P2.00mm_Vertical
QFN-28-1EP_5x5mm_P0.5mm_EP3.35x3.35mm
SOT-23
PGR_silkscreen
PGR_PCB

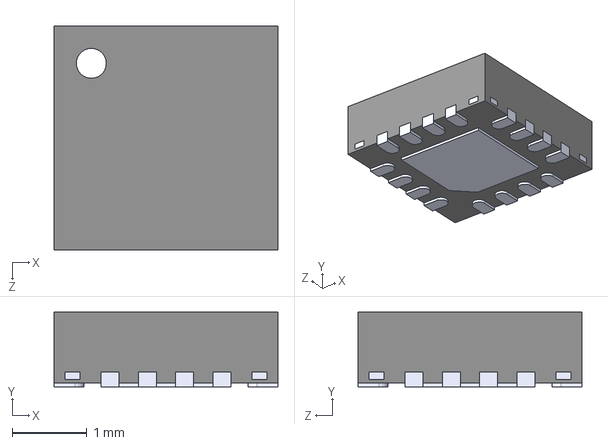
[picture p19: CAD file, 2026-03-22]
PGR - PCB/PGR - PCB/footprints/BQ24074RGT/BQ24074RGTR.STEP
3.00 x 1.00 x 3.00 mm

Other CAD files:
PGR - PCB/PGR.3mf

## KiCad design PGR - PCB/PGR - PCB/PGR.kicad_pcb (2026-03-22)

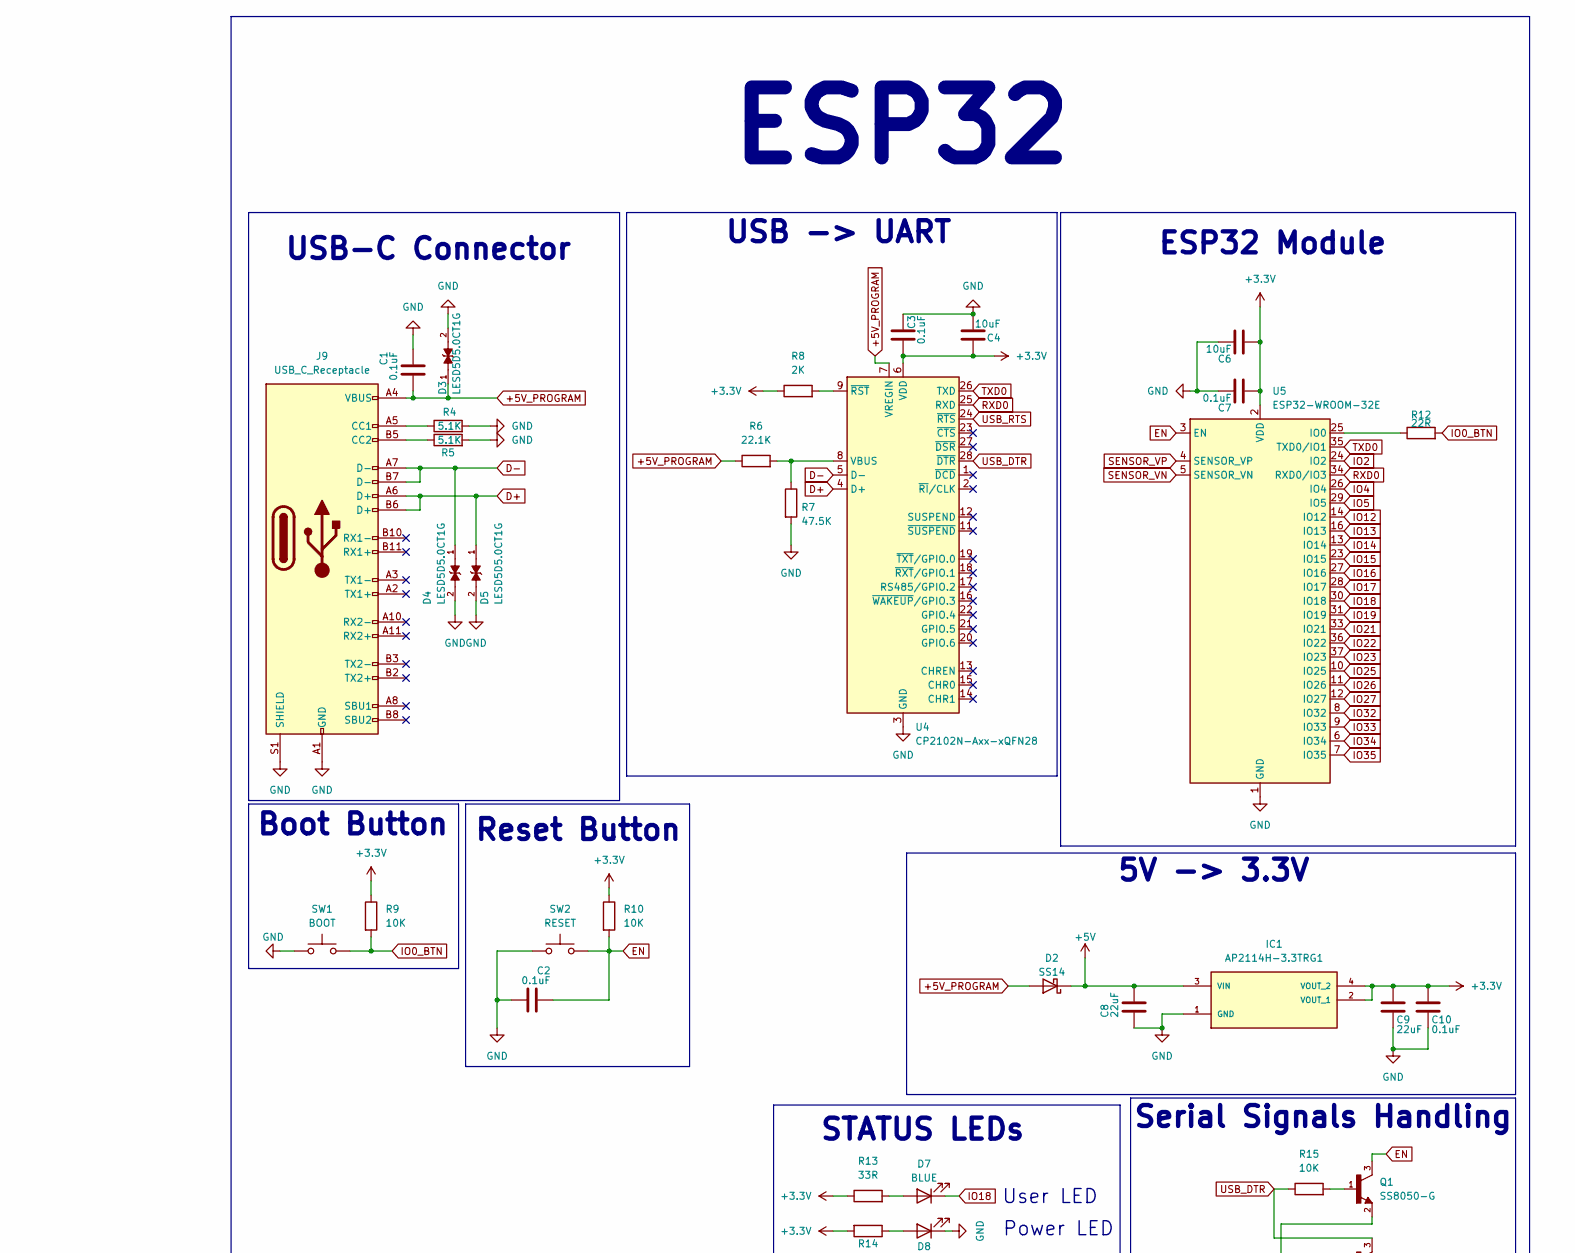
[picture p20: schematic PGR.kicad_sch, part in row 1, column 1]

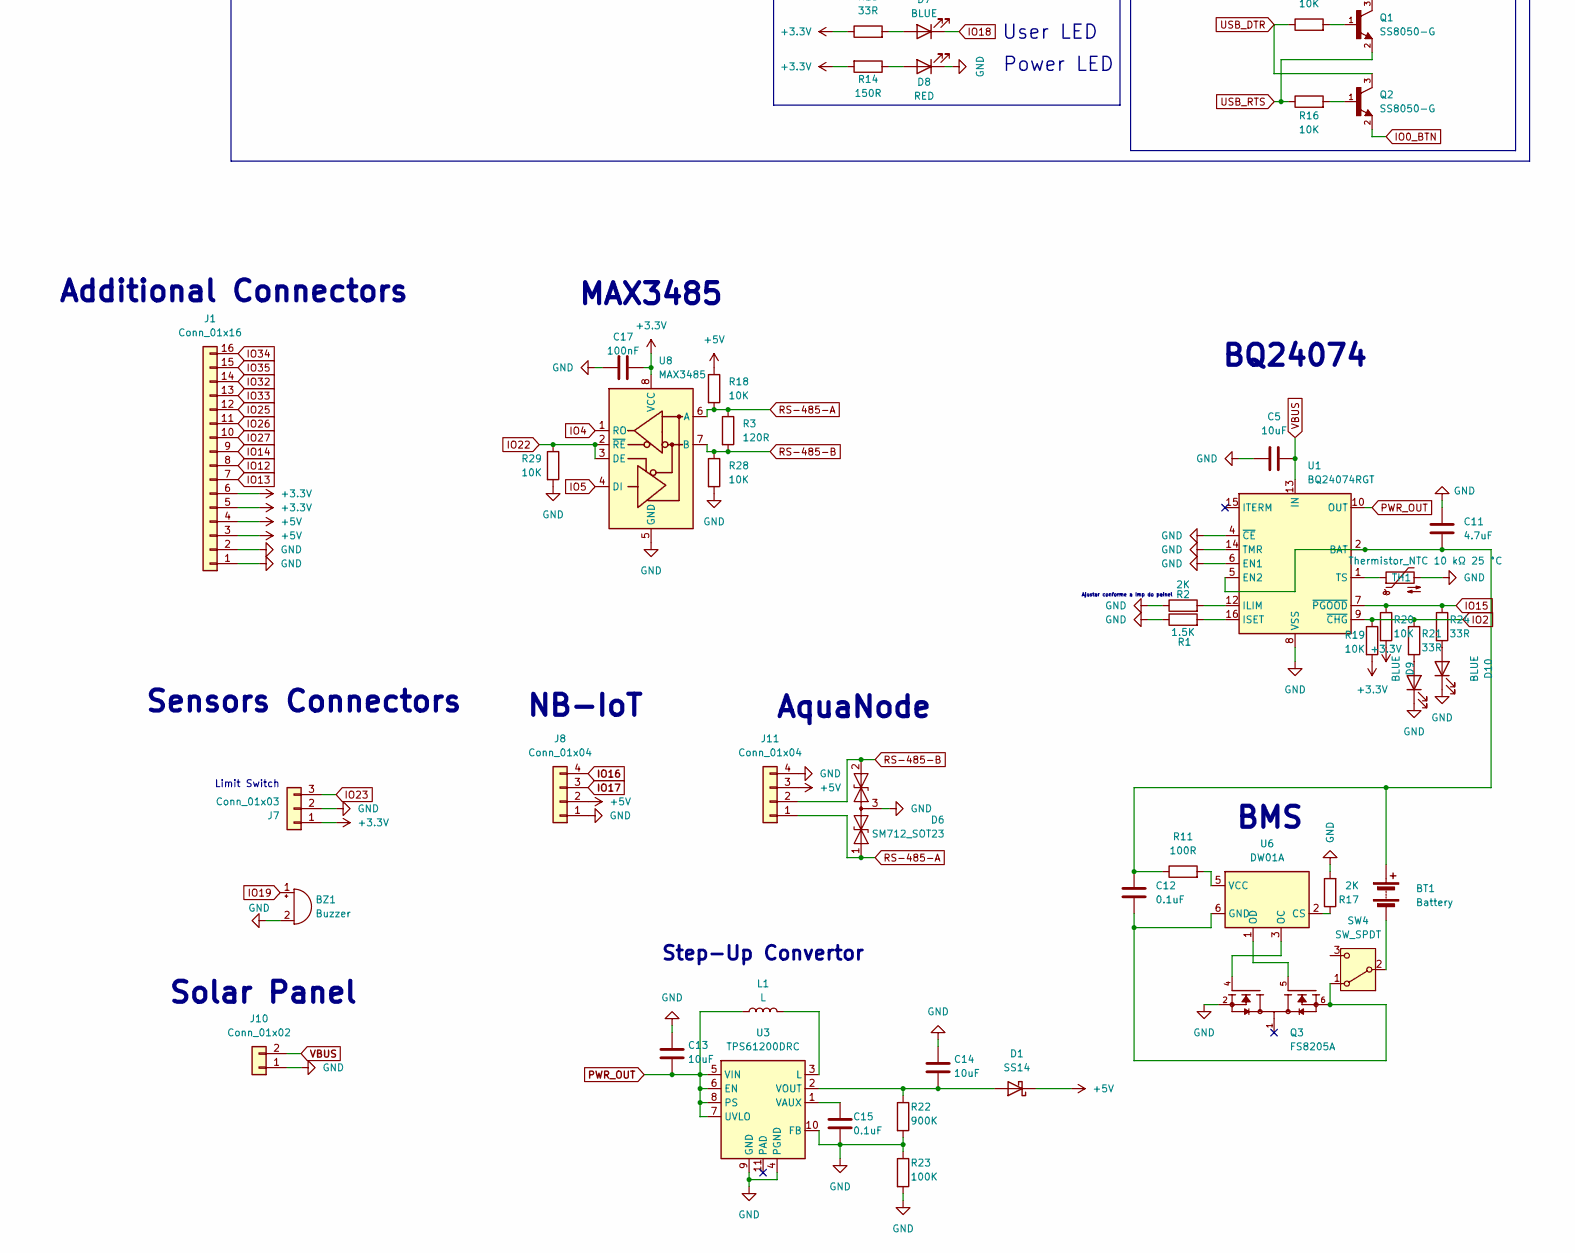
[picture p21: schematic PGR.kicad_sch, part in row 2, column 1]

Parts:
BT1: Battery; JST_XH_B2B-XH-A_1x02_P2.50mm_Vertical
BZ1: Buzzer; Buzzer_12x9.5RM7.6
C1, C2, C3, C7, C10, C12, C15: 0.1uF; C_0603_1608Metric
C4, C5, C6, C13, C14: 10uF; C_0805_2012Metric
C8, C9: 22uF; C_0805_2012Metric
C11: 4.7uF; C_0805_2012Metric
C17: 100nF; C_0603_1608Metric
D1, D2: SS14; D_SMA
D3, D4, D5: LESD5D5.0CT1G; TVS_LESD5D5.0CT1G; PARTREV O
D6: SM712_SOT23; SOT-23
D7, D9, D10: BLUE; LED_0603_1608Metric
D8: RED; LED_0603_1608Metric
IC1: AP2114H-3.3TRG1; SOT230P700X180-4N; MANUFACTURER_PART_NUMBER AP2114H-3.3TRG1
J1: Conn_01x16; PinSocket_1x16_P2.00mm_Vertical
J7: Conn_01x03; JST_XH_B3B-XH-A_1x03_P2.50mm_Vertical
J8, J11: Conn_01x04; JST_XH_B4B-XH-A_1x04_P2.50mm_Vertical
J9: USB_C_Receptacle; USB_C_Receptacle_GCT_USB4105-xx-A_16P_TopMnt_Horizontal
J10: Conn_01x02; JST_XH_B2B-XH-A_1x02_P2.50mm_Vertical
L1: L; L_0805_2012Metric
Q1, Q2: SS8050-G; TRANS_SS8050-G; PARTREV A
Q3: FS8205A; SOP65P640X120-8N; PARTREV 1.7
R1: 1.5K; R_0603_1608Metric
R2, R8, R17: 2K; R_0603_1608Metric
R3: 120R; R_0603_1608Metric
R4, R5: 5.1K; R_0603_1608Metric
R6: 22.1K; R_0603_1608Metric
R7: 47.5K; R_0603_1608Metric
R9, R10, R15, R16, R18, R19, R20, R28, R29: 10K; R_0603_1608Metric
R11: 100R; R_0603_1608Metric
R12: 22R; R_0603_1608Metric
R13, R21, R24: 33R; R_0603_1608Metric
R14: 150R; R_0603_1608Metric
R22: 900K; R_0603_1608Metric
R23: 100K; R_0603_1608Metric
SW1: BOOT; SW_SPST_B3U-1000P
SW2: RESET; SW_SPST_B3U-1000P
SW4: SW_SPDT; SW_DIP_SPSTx01_Slide_6.7x4.1mm_W6.73mm_P2.54mm_LowProfile_J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
TH1: Thermistor_NTC 10 kΩ 25 °C; R_Axial_DIN0309_L9.0mm_D3.2mm_P2.54mm_Vertical
U1: BQ24074RGT; VQFN-16-1EP_3x3mm_P0.5mm_EP1.6x1.6mm
U3: TPS61200DRC; Texas_S-PVSON-N10_ThermalVias
U4: CP2102N-Axx-xQFN28; QFN-28-1EP_5x5mm_P0.5mm_EP3.35x3.35mm
U5: ESP32-WROOM-32E; ESP32-WROOM-32D
U6: DW01A; SOT-23-6
U8: MAX3485; SOIC-8_3.9x4.9mm_P1.27mm

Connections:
+3.3V: C3.2, C4.2, C6.2, C7.2, C9.1, C10.1, C17.2, IC1.2 (VOUT_1), IC1.4 (VOUT_2), J1.5, J1.6, J7.1, R8.1, R9.1, R10.1, R13.1, R14.2, R19.2, R20.2, U4.6 (VDD), U5.2 (VDD), U8.8 (VCC)
+5V: C8.1, D1.1 (K), D2.1 (K), IC1.3 (VIN), J1.3, J1.4, J8.2, J11.3, R18.1
+5V_PROGRAM: C1.2, D2.2 (A), D3.1, J9.A4 (VBUS), J9.A9 (VBUS), J9.B4 (VBUS), J9.B9 (VBUS), R6.1, U4.7 (VREGIN)
D+: D5.1, J9.A6 (D+), J9.B6 (D+), U4.4 (D+)
D-: D4.1, J9.A7 (D-), J9.B7 (D-), U4.5 (D-)
EN: C2.1, Q1.3, R10.2, SW2.2, U5.3 (EN)
GND: BZ1.2 (-), C1.1, C2.2, C3.1, C4.1, C5.1, C6.1, C7.1, C8.2, C9.2, C10.2, C11.1, C13.1, C14.1, C15.2, C17.1, D3.2, D4.2, D5.2, D6.3 (common), D8.1 (K), D9.1 (K), D10.1 (K), IC1.1 (GND), J1.1, J1.2, J7.2, J8.1, J9.A1 (GND), J9.A12 (GND), J9.B1 (GND), J9.B12 (GND), J9.S1 (SHIELD), J10.1, J11.4, Q3.2, Q3.3, R1.1, R2.1, R4.2, R5.2, R7.2, R17.2, R22.2, R23.1, R23.2, R28.2, R29.2, SW1.1, SW2.1, TH1.2, U1.4 (~CE), U1.6 (EN1), U1.8 (VSS), U1.14 (TMR), U1.17 (VSS), U3.4 (PGND), U3.9 (GND), U3.10 (FB), U4.3 (GND), U4.29 (GND), U5.1 (GND), U5.15 (GND), U5.38 (GND), U5.39 (GND), U8.5 (GND)
IO0_BTN: Q2.2, R9.2, R12.2, SW1.2
IO2: R19.1, R21.1, U1.9 (~CHG), U5.24 (IO2)
IO4: U5.26 (IO4), U8.1 (RO)
IO5: U5.29 (IO5), U8.4 (DI)
IO12: J1.8, U5.14 (IO12)
IO13: J1.7, U5.16 (IO13)
IO14: J1.9, U5.13 (IO14)
IO15: R20.1, R24.1, U1.7 (~PGOOD), U5.23 (IO15)
IO16: J8.4, U5.27 (IO16)
IO17: J8.3, U5.28 (IO17)
IO18: D7.1 (K), U5.30 (IO18)
IO19: BZ1.1 (+), U5.31 (IO19)
IO21: U5.33 (IO21)
IO22: R29.1, U5.36 (IO22), U8.2 (~RE), U8.3 (DE)
IO23: J7.3, U5.37 (IO23)
IO25: J1.12, U5.10 (IO25)
IO26: J1.11, U5.11 (IO26)
IO27: J1.10, U5.12 (IO27)
IO32: J1.14, U5.8 (IO32)
IO33: J1.13, U5.9 (IO33)
IO34: J1.16, U5.6 (IO34)
IO35: J1.15, U5.7 (IO35)
unnamed: BT1.1 (+), C11.2, C12.1, R11.1, U1.2 (BAT), U1.3 (BAT), U1.5 (EN2)
unnamed: BT1.2 (-), SW4.2 (B)
unnamed: C14.2, D1.2 (A), R22.1, U3.2 (VOUT)
unnamed: D7.2 (A), R13.2
unnamed: D8.2 (A), R14.1
unnamed: D9.2 (A), R21.2
unnamed: D10.2 (A), R24.2
unnamed: J9.A5 (CC1), R4.1
unnamed: J9.B5 (CC2), R5.1
unnamed: Q1.1, R15.2
unnamed: Q2.1, R16.2
unnamed: C12.2, Q3.6, Q3.7, SW4.1 (A), U6.6 (GND)
unnamed: R2.2, U1.12 (ILIM)
unnamed: R1.2, U1.16 (ISET)
unnamed: TH1.1, U1.1 (TS)
unnamed: L1.2, U3.3 (L)
unnamed: C15.1, U3.1 (VAUX)
unnamed: R6.2, R7.1, U4.8 (VBUS)
unnamed: R8.2, U4.9 (~RST)
unnamed: R12.1, U5.25 (IO0)
unnamed: R17.1, U6.2 (CS)
unnamed: Q3.4, U6.3 (OC)
unnamed: Q3.5, U6.1 (OD)
unnamed: R11.2, U6.5 (VCC)
PWR_OUT: C13.2, L1.1, U1.10 (OUT), U1.11 (OUT), U3.5 (VIN), U3.6 (EN), U3.7 (UVLO), U3.8 (PS)
RS-485-A: D6.1 (A1), J11.1, R3.1, R18.2, U8.6 (A)
RS-485-B: D6.2 (A2), J11.2, R3.2, R28.1, U8.7 (B)
RXD0: U4.25 (RXD), U5.34 (RXD0/IO3)
SENSOR_VN: U5.5 (SENSOR_VN)
SENSOR_VP: U5.4 (SENSOR_VP)
TXD0: U4.26 (TXD), U5.35 (TXD0/IO1)
USB_DTR: Q2.3, R15.1, U4.28 (~DTR)
USB_RTS: Q1.2, R16.1, U4.24 (~RTS)
VBUS: C5.2, J10.2, U1.13 (IN)

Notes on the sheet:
Sensors Connectors
STATUS LEDs
MAX3485
NB-IoT
ESP32 Module
Limit Switch
Ajustar conforme a Imp do painel
ESP32
Additional Connectors
User LED
BMS
Solar Panel
5V -> 3.3V
Step-Up Convertor
BQ24074
USB -> UART
Boot Button
Power LED
USB-C Connector
Reset Button
Serial Signals Handling
AquaNode

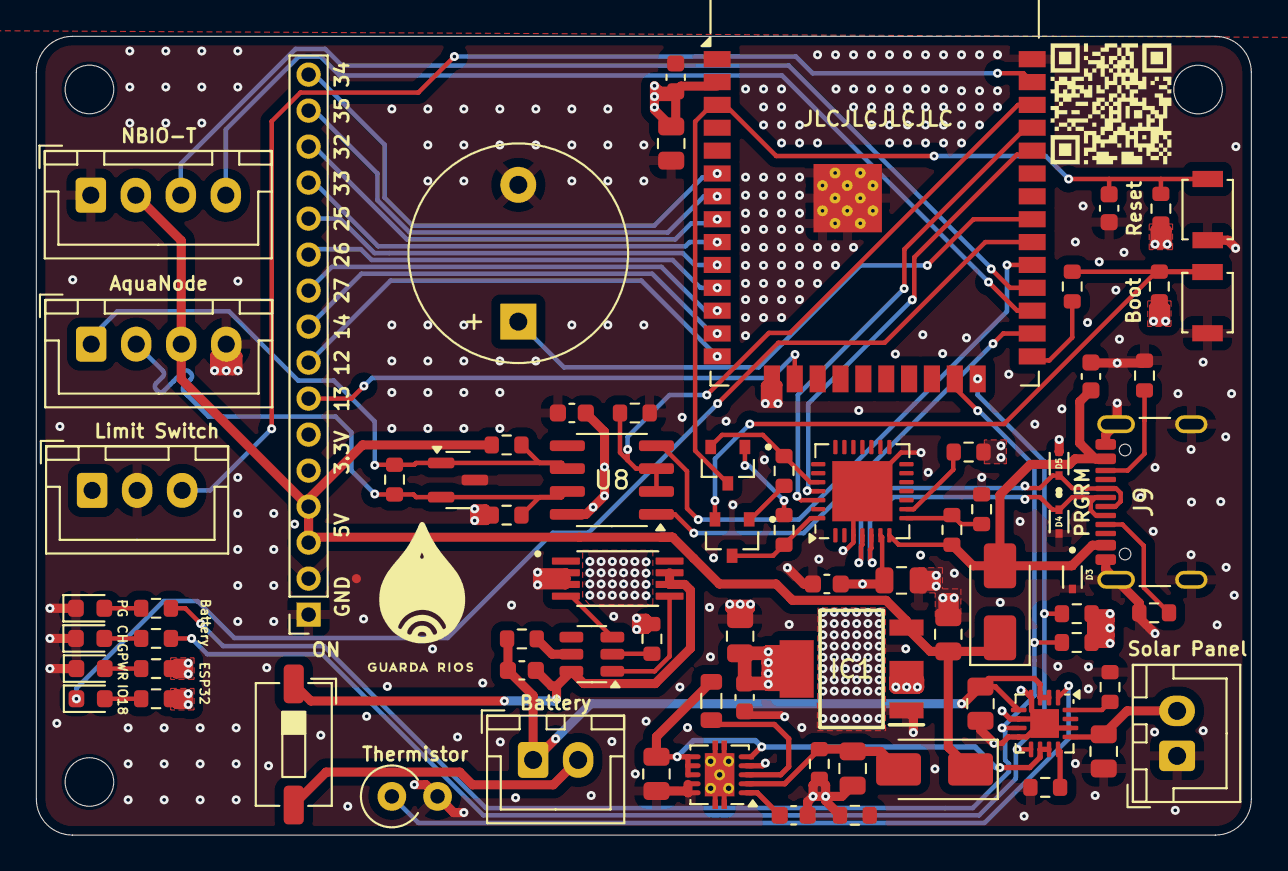
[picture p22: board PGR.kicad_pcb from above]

Board: 4 copper layers, 67.5 x 44.4 mm, 75 parts (0 on the bottom side), 60 nets.

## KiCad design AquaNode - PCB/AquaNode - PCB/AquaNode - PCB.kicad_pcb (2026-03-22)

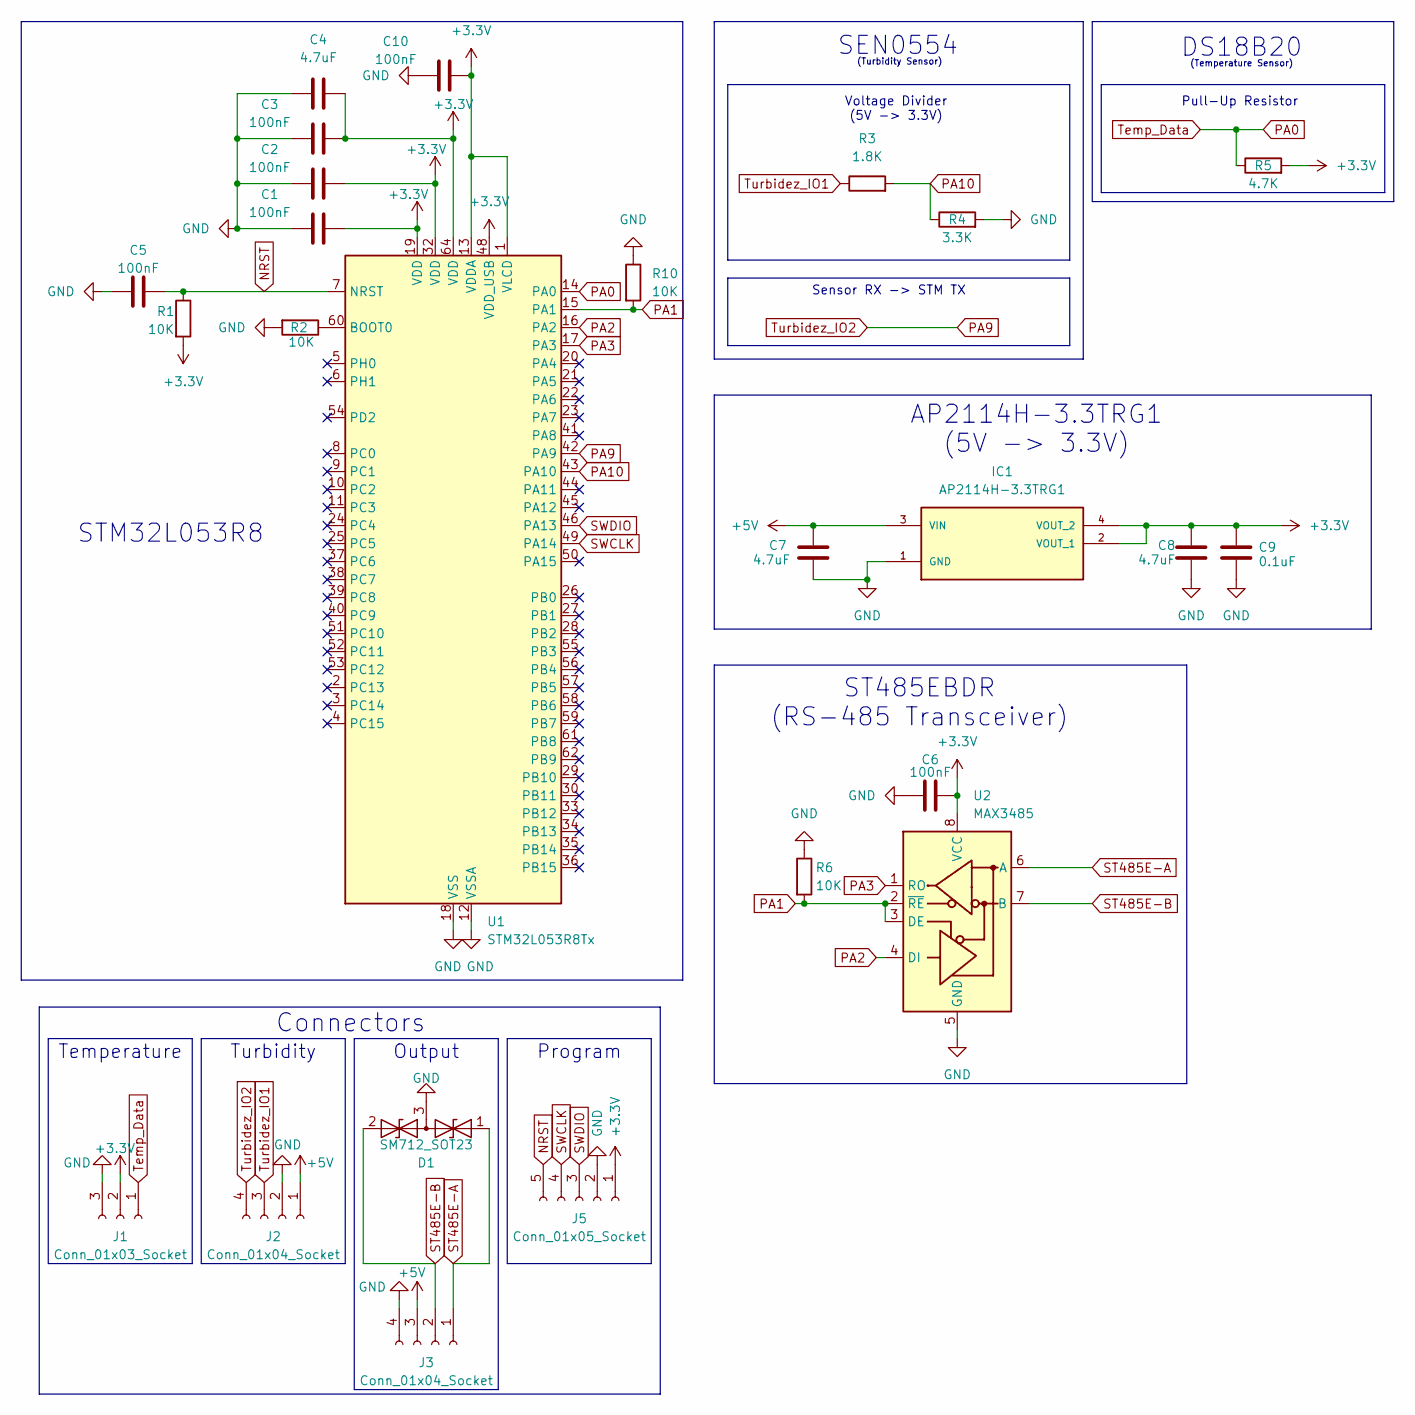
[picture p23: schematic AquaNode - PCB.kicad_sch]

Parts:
C1, C2, C3, C5, C6, C10: 100nF; C_0603_1608Metric
C4, C7, C8: 4.7uF; C_0603_1608Metric
C9: 0.1uF; C_0603_1608Metric
D1: SM712_SOT23; SOT-23
IC1: AP2114H-3.3TRG1; SOT230P700X180-4N; MANUFACTURER_PART_NUMBER AP2114H-3.3TRG1
J1: Conn_01x03_Socket; JST_EH_B3B-EH-A_1x03_P2.50mm_Vertical
J2, J3: Conn_01x04_Socket; JST_EH_B4B-EH-A_1x04_P2.50mm_Vertical
J5: Conn_01x05_Socket; PinHeader_1x05_P2.54mm_Vertical
R1, R2, R6, R10: 10K; R_0603_1608Metric
R3: 1.8K; R_0603_1608Metric
R4: 3.3K; R_0603_1608Metric
R5: 4.7K; R_0603_1608Metric
U1: STM32L053R8Tx; LQFP-64_10x10mm_P0.5mm
U2: MAX3485; SOIC-8_3.9x4.9mm_P1.27mm

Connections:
+3.3V: C1.2, C2.2, C3.2, C4.2, C6.2, C8.1, C9.1, C10.2, IC1.2 (VOUT_1), IC1.4 (VOUT_2), J1.2, J5.1, R1.2, R5.2, U1.1 (VLCD), U1.13 (VDDA), U1.19 (VDD), U1.32 (VDD), U1.48 (VDD_USB), U1.64 (VDD), U2.8 (VCC)
+5V: C7.1, IC1.3 (VIN), J2.1, J3.3
GND: C1.1, C2.1, C3.1, C4.1, C5.1, C6.1, C7.2, C8.2, C9.2, C10.1, D1.3 (common), IC1.1 (GND), J1.3, J2.2, J3.4, J5.2, R2.2, R4.2, R6.1, R10.1, U1.12 (VSSA), U1.18 (VSS), U1.31 (VSS), U1.47 (VSS), U1.63 (VSS), U2.5 (GND)
NRST: C5.2, J5.5, R1.1, U1.7 (NRST)
unnamed: R2.1, U1.60 (BOOT0)
PA0: J1.1, R5.1, U1.14 (PA0)
PA1: R6.2, R10.2, U1.15 (PA1), U2.2 (~RE), U2.3 (DE)
PA2: U1.16 (PA2), U2.4 (DI)
PA3: U1.17 (PA3), U2.1 (RO)
PA9: J2.4, U1.42 (PA9)
PA10: R3.2, R4.1, U1.43 (PA10)
ST485E-A: D1.1 (A1), J3.1, U2.6 (A)
ST485E-B: D1.2 (A2), J3.2, U2.7 (B)
SWCLK: J5.4, U1.49 (PA14)
SWDIO: J5.3, U1.46 (PA13)
Turbidez_IO1: J2.3, R3.1

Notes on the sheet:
ST485EBDR (RS-485 Transceiver)
AP2114H-3.3TRG1 (5V -> 3.3V)
Program
DS18B20
Sensor RX -> STM TX
Output
Pull-Up Resistor
Connectors
Voltage Divider (5V -> 3.3V)
Temperature
SEN0554
(Temperature Sensor)
STM32L053R8
Turbidity
(Turbidity Sensor)

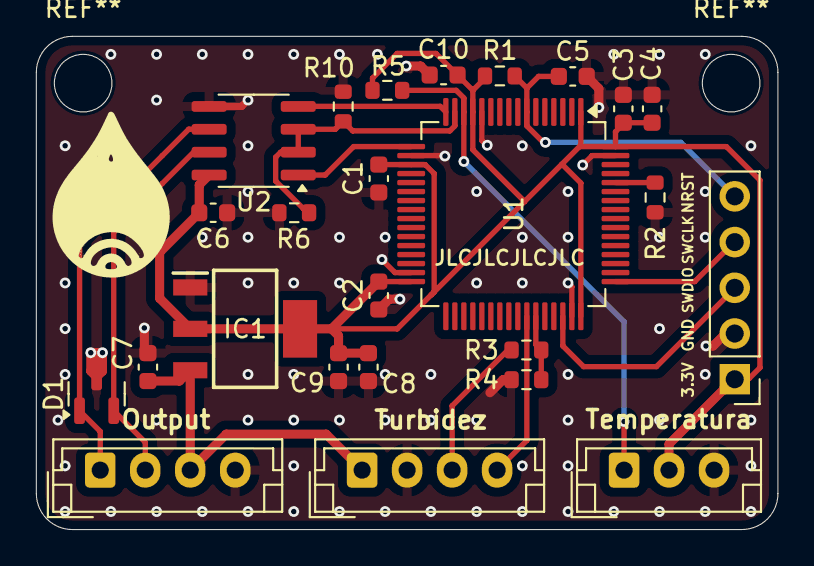
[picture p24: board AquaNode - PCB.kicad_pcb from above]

Board: 2 copper layers, 41.2 x 27.4 mm, 25 parts (0 on the bottom side), 16 nets.

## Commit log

2025-05-18 Initial Commit🎉
    Adicionado os arquivos da PCB
    [E32-900T30D-PcbLib.PcbLib, PGR.kicad_pcb, PGR.kicad_sch]
2025-05-28 Adicionado um refresh button dos gráficos...
2026-03-22 Updated the PCBs to the most recent ones!
    [-v2.0_bom.csv, -v2.0_designators.csv, -v2.0_positions.csv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]
2026-10-26 Save PCB project state and solar power reliability updates
    Save all current project changes and assets, including the reviewed PGR
    power and ground repairs, solar charging controls, charge timer, and remote
    battery-temperature connector in the schematic and routed PCB.
2026-10-26 Preserve local KiCad history snapshots as project files
2026-10-26 Save complete main worktree before reviewed board update
    Include current PCB files, project assets, and local KiCad history snapshots.
2026-10-27 Update PGR schematic and PCB component selections
2026-10-27 Preserve current PGR board placement and routing
2026-10-27 Replace J1 with four-pin spare ESP32 GPIO header
2026-10-27 Expose spare and shared JTAG GPIOs on eight-pin expansion header
2026-10-27 Save current PGR board, schematic and project changes
2026-11-01 Add battery temperature and power safety circuitry
2026-11-01 Prioritize USB power and increase USB current limit
    Set R37 to 160 ohms with 1% tolerance, configure U7 for USB priority, and coordinate its divider with charger input-voltage regulation. Update PCB routing, parallel BOOST_5V vias, source-status naming, and small-button part metadata.
    Validation: zero electrical DRC errors, zero unconnected items, zero schematic-parity issues, and zero unexcluded ERC issues. Existing silkscreen and footprint-library warnings remain.
